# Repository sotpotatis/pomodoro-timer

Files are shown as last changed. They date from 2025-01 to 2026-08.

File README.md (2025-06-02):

# Pomodoro Timer

## What is this?

This Project aims to create a portable Pomodoro timer that you can carry around with you - regardless if studying in the library, on the bus, or in the Comfort of your own home!

### Components and technology

#### Programming languages

The main part of this Project is programmed in AVR Assembly. Some parts are coded in C.

#### Main Components used

* Attiny84A

* DS3231 timer

#### Building the Circuit/assembling the PCB

For the full description on how to build the Project, I will at some Point (**TODO**) provide documentation about how to assemble your own Pomodoro timer.

## Development

Under the `code` folder you will find a solution which you can import into Microchip Studio (version 7).

You also need to add the files `i2cmaster.h` and `i2cmaster.S` which are from Peter Fleury's I2CMaster library (can be found [here](http://www.peterfleury.epizy.com/avr-software.html?i=1))

Inside `tests` you will find various tests carried out during the project - please see the `README` inside that directory.

## Documentation

See the `docs` folder for Project documentation.

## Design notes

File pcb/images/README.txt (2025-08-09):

This directory contains all the images that are used (as silkscreen items) on the PCB.
It also contains project files to so you can modify the images.

# Regarding the icons underneath the buttons

After loading the icons in the KiCads bitmap converter, set "Lock height/width ratio" to True and set "Width" to 12mm. This will give you the same sizing as is used on the board.

# Regarding `bell_icon`

After loading the icons in the KiCads bitmap converter, set "Lock height/width ratio" to True and set "Width" to 1.75mm. This will give you the same sizing as is used on the board.

*The bell icon is from [Pictogrammers](https://github.com/Templarian/MaterialDesign) and released under an Apache 2.0 License.*
See [https://github.com/Templarian/MaterialDesign/blob/master/LICENSE](here).

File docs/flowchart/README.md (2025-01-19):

# Flowchart files

Here you are going to find a flowchart of how the main timer logic is laid out. What does what? Look here to find out!

The flowchart can be imported to https://app.diagrams.net.

**Note** that the PDF version is less likely to be up-to-date (reflect the current version of the flowchart file) that the `.drawio` version of the file.

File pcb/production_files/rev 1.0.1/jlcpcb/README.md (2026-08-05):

I used PCBWay (not JLCPCB) when I ordered my Pomodoro Timer PCBs, becuase their assembly service was a bit cheaper for the setup I wanted (a blue or black PCB).

That said, the files in this directory should be "sendable" to JLCPCB. Use the following files:

* `rev1.0.1` is a .zip-file with all the gerbers

* `bom.xls` is the BOM file (for the assembly service)

* `sotpotatis_pomodoro_timer-all-pos.csv` is the positions file (for the assembly service)

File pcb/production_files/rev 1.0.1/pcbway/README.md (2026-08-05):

# Ordering instructions

If you want to order the PCB from PCBWay, here's what files to use:

* The file `gerbers_bom_and_cpl.zip` in `sotpotatis_pomodoro_timer.kicad_pcb` can be uploaded when requested to provide files related to the PCB (*not the assembly service*).

* The `.zip` file just mentioned includes both the BOM and CPL (i.e. the files required for the assembly service), but it turns out you need to supply them separately (PCBWay's upload form doesn't magically detect that you have provided a .zip file with both production and assembly files). Thus, *for the assembly service*, you should also upload `PCBWay_bom.csv` and `PCBWay_positions.csv` found in the `sotpotatis_pomodoro_timer.kicad_pcb` directory (or in the `.zip` file, it doesn't matter, they are the same files).

> For a visual image, see `sample_pcbway_order_information.png`. It shows a brief outlines of the files and settings I used when ordering the PCB.

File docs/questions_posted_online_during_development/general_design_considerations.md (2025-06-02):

Hello!

I am working on a project where I am trying to create a timer using an Attiny microcontroller.
I do not mention the model name of the Attiny, because it is not set in stone due to that I have a couple of different configurations in mind.

Let me explain the main goals and requirements of this project (skip to "the hardware I need to include" if you want to, the questions are related to those):

* Create a timer in the form factor of a credit card, powered by batteries (my plan is CR2032/26)
* The timer will allow counting down from 1 minute - 120 minutes.
* The time left will be displayed by using 12 LEDs arranged in a progress bar pattern. As the time left decreases, the number of lit LEDs decrease.
The last LED that is on in the pattern will be blinking every second to indicate countdown.
See the image here <ADD IMAGE> for what I mean:
* The user should allow setting 3 timer presets (for example, if you often count down to 30 minutes, you should be able to save it and load it)
* The timeout should be indicated by sounding a buzzer.
* The purpose of the timer is to be used for focus work sessions (e.g. studying on the go), so it is going to allow to user to select the time they want to work, 
the time they want to take a break, and how many times that should be repeated.
    * A consequence of the just mentioned requirement is that I want to add 3 LEDs on top of the 12 LEDs to indicate if the user is "working", "resting", or "setting the time".

Software requirements:
* For learning purposes, I would implement the main parts of the program in AVR Assembly. (Feel free to ramble as much as you want about that, but I have experience with C and I want to challenge myself.) (the I2C timer interaction, I'm doin' that in C. Don't worry.)

Thus, the hardware I need to include:

* 5 buttons (2 for timer settings (+/- time), 3 preset buttons) 
* 15 LEDs (12 for countdown time, 3 for timer state display)
* Timer
* Buzzer to indicate timeout

So to my questions.

# Question 1: Charlieplexing timer

## Background

Assuming the buzzer can be driven by some kind of square wave output from my timer (for example MCP7940M offers a 1Hz square wave output), I would need:

5 button GPIOs + 15 LEDs + 2 timer I2C GPIOs + 1 timer interrupt pin = 23 pins

A method to control n(n-1) LEDs with n pins is Charlieplexing. I am considering Charlieplexing the 12 pin progressbar, requiring a 4-pin setup. You can read all about it here: https://circuitdigest.com/microcontroller-projects/charlieplexing-arduino-to-control-12-leds-with-4-gpio-pins

So, I have come up with a code that works on an Arduino UNO for what I am trying to do: 

## Actual question

My "Charlieplexing" tests require a delay of 1000us to lit all LEDs without them appearing blinking to the human eye.
I was considering using an external timer to generate 1000us interrupts, but I can't find such timer and I assume that would be too fast for the device to handle.
How bad is it to use the internal Attiny timer for such short periods? The specs hint that it is quite inaccurate. Any alternatives I should consider? If precise timing isn't used, since Charlieplexing requires turning on and off LEDs super fast each second so all LEDs appear lit to the human eye, the LEDs appear to have different brightness.

And yeah, Charlieplexing requires turning on and off LEDs super fast each second so all LEDs appear lit to the human eye. I assume this rapid on/off would draw more power than just having them on all the time?

# Question 2: Charlieplexing - other alternatives

I may considering changing to shift registers, they seem easier. Read question 1 for more context. Anyone have experience controlling 12 GPIOs with less than 12 pins (in my case Charlieplexing allows me to use 4)? What other alternatives should I consider? How much better is shift registers?

# Question 3: External timer choice

I am planning on counting down the timer by generating timer interrupts every second to an interrupt pin, making the device decrement a "time left" variable. I also need the timer to beep a buzzer every second once the timer has run out.

I am currently considering the MCP7940M timer: does anyone have experience? And it would cost as many pins to use I2C as to connect a crystal to the Attiny and use the internal timer, so I am considering doing that instead. Is it visable?

# Question 4: Button interrupts

I want each of the 5 buttons to generate an interrupt if you click them. I've heard that hardware interrupts can be a pain with buttons unless you take some precautions. I have done research for question 1-3, but I admit this one not that much. Is it viable to use hardware interrupts for buttons? What precautions should I take when designing the hardware? Should I consider polling instead? I think that interrupts will be cleaner and more power efficient, hence why I am using that.

Sorry if this was a lot of questions, I'd be happy to just get an answer to a few of them :)

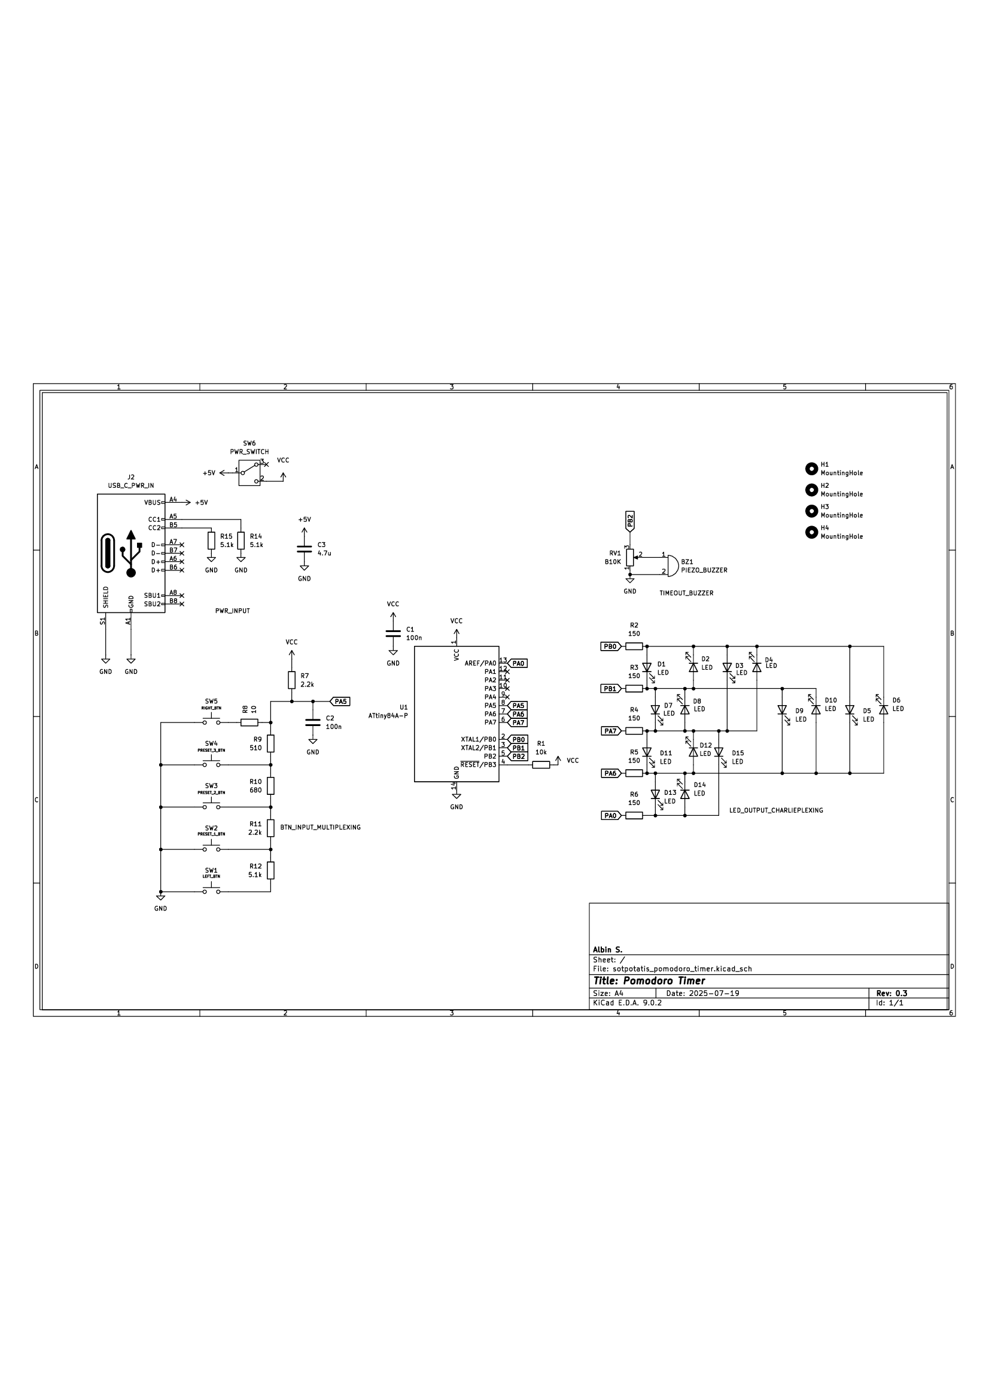
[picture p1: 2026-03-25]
pcb/pdfs/PCB reviews/Review 1 (rev1.0.0)/schematics 1 of 1.png

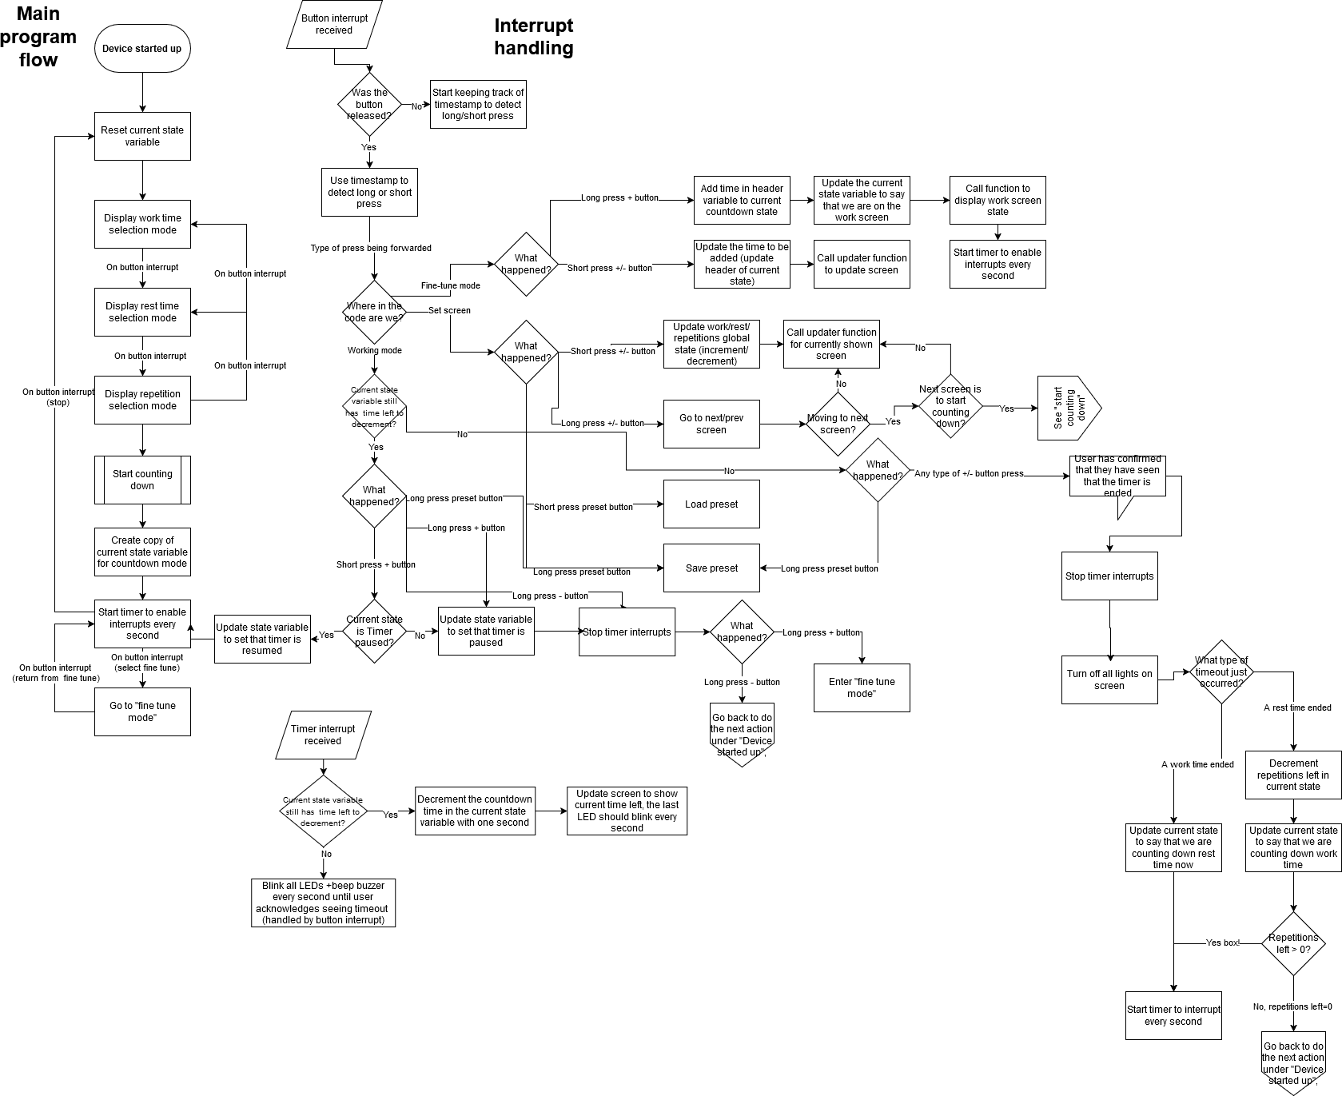
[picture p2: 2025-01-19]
docs/flowchart/Pomodoro timer flowchart.drawio.png

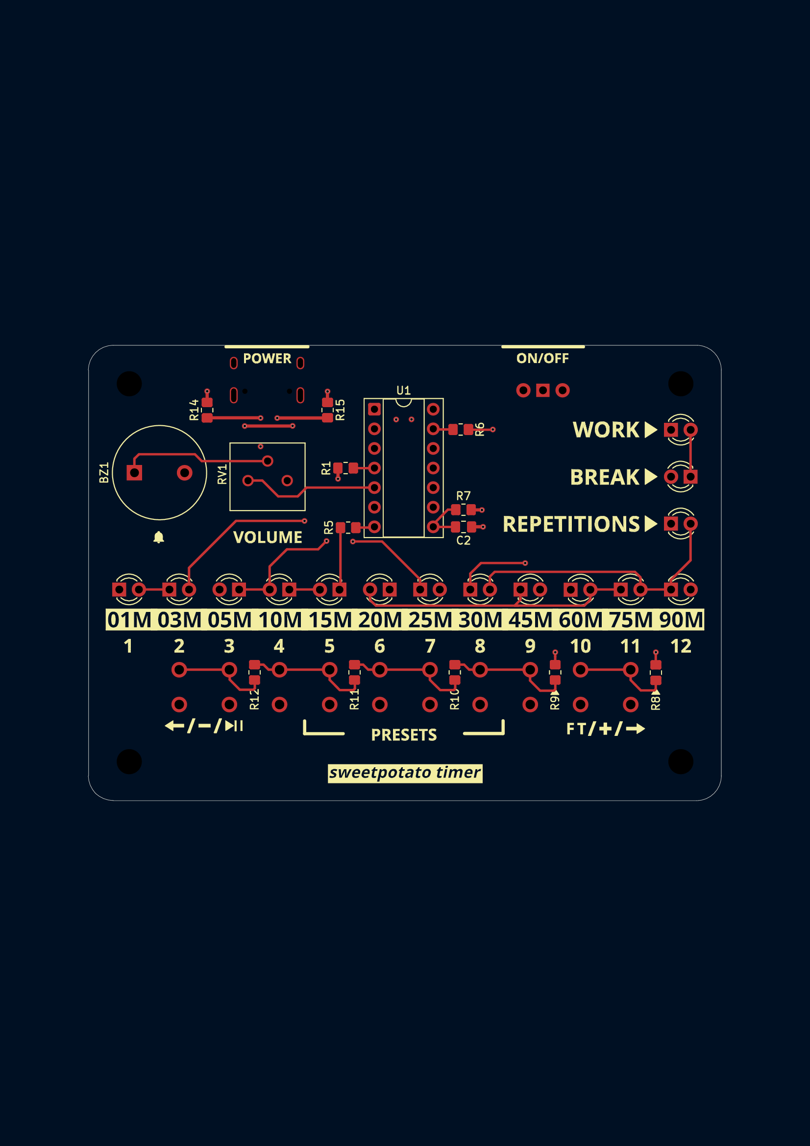
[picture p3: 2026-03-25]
pcb/pdfs/PCB reviews/Review 1 (rev1.0.0)/front-copper 1 of 1.png

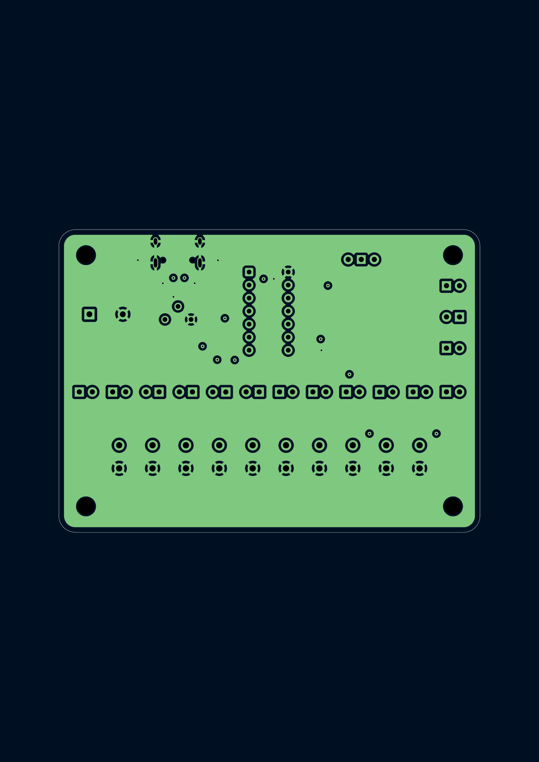
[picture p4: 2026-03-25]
pcb/pdfs/PCB reviews/Review 1 (rev1.0.0)/in1-copper 1 of 1.png

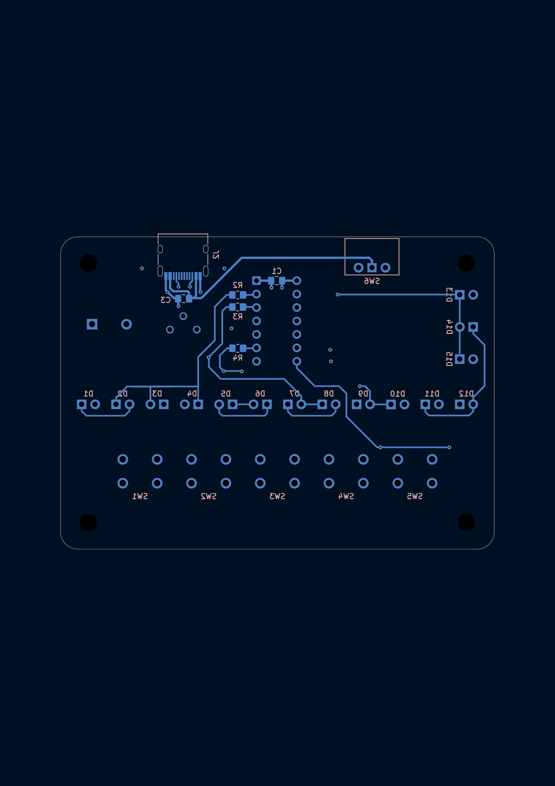
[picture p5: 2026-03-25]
pcb/pdfs/PCB reviews/Review 1 (rev1.0.0)/back-copper 1 of 1.png

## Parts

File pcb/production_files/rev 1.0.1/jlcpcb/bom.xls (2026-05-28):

Comment | Designator | Footprint | JLCPCB Part#(optional)
16P USB-C 2.0 | J2 | SMD-16P-USB-C | C165948
10kΩ | R1 | 0805_R | C17414
150Ω | R2-6 | 0805_R | C17471
2.2kΩ | R7,R11 | 0805_R | C17520
10Ω | R8 | 0805_R | C25278
510Ω | R9 | 0805_R | C17734
680Ω | R10 | 0805_R | C17798
5.1kΩ | R12,R14-15 | 0805_R | C27834
100nF | C1-2 | 0805_C | C28233
4.7uF | C3 | 0805_C | C1779

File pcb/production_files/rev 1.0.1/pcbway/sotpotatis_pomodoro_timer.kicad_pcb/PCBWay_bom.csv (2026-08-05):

Designator | Quantity | Value | Footprint | Package | MPN | Mount_Type | Description
C1, C2 | 2 | 100nF | Unpolarized_Capacitor_0805 | 805 | CL21B104KCFNNNE | smt | Ceramic Capacitor 100nF 100V X7R 0805
C3 | 1 | 4.7uF | Unpolarized_Capacitor_0805 | 805 | CL21A475KAQNNNE | smt | Ceramic Capacitor 4.7uF 25V X5R 0805
J2 | 1 |  | USB_C_Receptacle_HRO_TYPE-C-31-M-12 | 16P USB-C | Hroparts TYPE-C-31-M-12 | smt | 20V 5A 16P Right-Angle USB2.0 Type-C Female Receptacle connector
R1 | 1 | 10kΩ | Resistor_0805 | 805 | 0805W8F1002T5E | smt | Resistor 150V 10kΩ ±1% 125mW 0805
R10 | 1 | 680Ω | Resistor_0805 | 805 | 0805W8F6800T5E | smt | Resistor 150V 680Ω ±1% 125mW 0805
R11, R7 | 2 | 2.2kΩ | Resistor_0805 | 805 | 0805W8F2201T5E | smt | Resistor 150V 2.2kΩ ±1% 125mW 0805
R12, R14, R15 | 3 | 5.1kΩ | Resistor_0805 | 805 | 0805W8F5101T5E | smt | Resistor 150V 5.1kΩ ±1% 125mW 0805
R2, R3, R4, R5, R6 | 5 | 150Ω | Resistor_0805 | 805 | 0805W8F1500T5E | smt | Resistor 150V 150Ω ±1% 125mW 0805
R8 | 1 | 10Ω | Resistor_0805 | 805 | 0805W8J0100T5E | smt | Resistor 150V 10Ω ±5% 125mW 0805
R9 | 1 | 510Ω | Resistor_0805 | 805 | 0805W8F5100T5E | smt | Resistor 150V 510Ω ±1% 125mW 0805

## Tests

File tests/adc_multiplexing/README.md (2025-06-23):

# ADC multiplexing tests

The files in this directory are as follows:

1. `adc_muliplexing_schematics.fzz` - A Fritzing project which has the schematics of the ADC multiplexing circuits and a stripboard translation of it.
However, it has never been built, so it might be incorrect.

> **ℹ️Note:** The main algorithm for ADC multiplexing was taught to me by patient AVRFreaks forums user `avrcandies`. I thank you very very much for the help!
> [This is the topic that they helped me in](www.avrfreaks.net/s/topic/a5CV40000003RbZMAU/t400824?page=2).

2. `Arduino Tests` - Contains test sketches used on an Arduino Uno to validate the multiplexing circuit and the actual algorithm.

3. `C Code, migrated to ASM nowadays` - Contains source code of `getCurrentADCButton` and `updateButtonStates` functions before they were translated to Assembly. 
Their Assembly translations have made it into the "real" source code, see adcMultiplexing.S.

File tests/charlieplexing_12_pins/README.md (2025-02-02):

# Charlieplexing 12 pins

For controlling each of the LEDs that are used for indicating the time left on the timer without having to use 12 pins for 12 LEDs, I used a technique called Charlieplexing.

Below is an explanation of the different files in this directory:

* `code/charlieplexing_12_leds/charlieplexing_12_leds.ino`: Code to test Charlieplexing up to 12 LEDs, with the last LED blinking. Proof of concept, does not neccessarily have to run on an Attiny microcontroller.

* `schematics/Charlieplexing 12 LEDs.fzz`: Fritzing project to build Charlieplexing 12 LEDs. Has a schematic grouped by pin, however, the breadboard is not cleanly routed and all connections are not correct. I must have done something wrong since Fritzings routing did not cooperate with me. **The breadboard layout in this file is not buildable**.

* `schematics/Charlieplexing 12 LEDs - Cleaned up breadboard version.fzz`: See  `schematics/Charlieplexing 12 LEDs.fzz`. The difference is that here, I routed the connections manually, **so this file is the one who has what I think is a somewhat understandable and buildable 12 LED charlieplexing circuit**.

* `schematics/Charlieplexing 12 LEDs - Alternative version with classical schematics.fzz`: Fritzing project to build Charlieplexing 12 LEDs. Breadboard connections unrouted. The interesting tab here is the "Schematics" tab, where a classical 4-pin Charlieplexing schematic is drawn, in the typical way that these schematics are drawn (not grouped by pin as for the other `.fzz` files, which are more intuitive for breadboard or routing in my opinion.)

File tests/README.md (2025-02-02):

# Tests folder

Here you will find out various tests carried out throughout the project. Please see the `README` files of each respective folder for more information.

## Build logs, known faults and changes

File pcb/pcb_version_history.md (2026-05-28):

# PCB version history

## rev1.0.1

* Same as rev1.0.0, *but* all SMD components have now been put on the back of the board. This was done in order to save assembly costs when using an Assembly Service (like JLCPCB)

## rev1.0.0

* Initial version of the Pomodoro Timer PCB.

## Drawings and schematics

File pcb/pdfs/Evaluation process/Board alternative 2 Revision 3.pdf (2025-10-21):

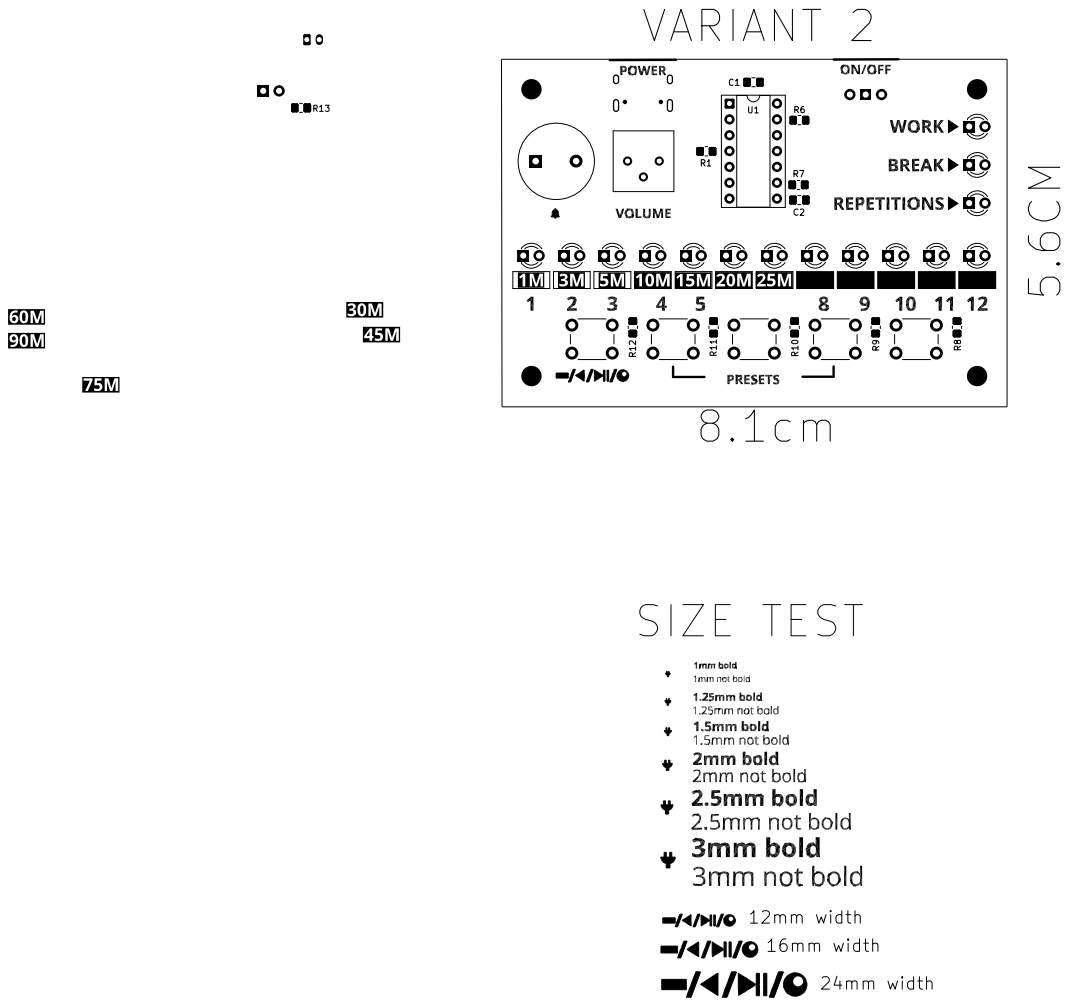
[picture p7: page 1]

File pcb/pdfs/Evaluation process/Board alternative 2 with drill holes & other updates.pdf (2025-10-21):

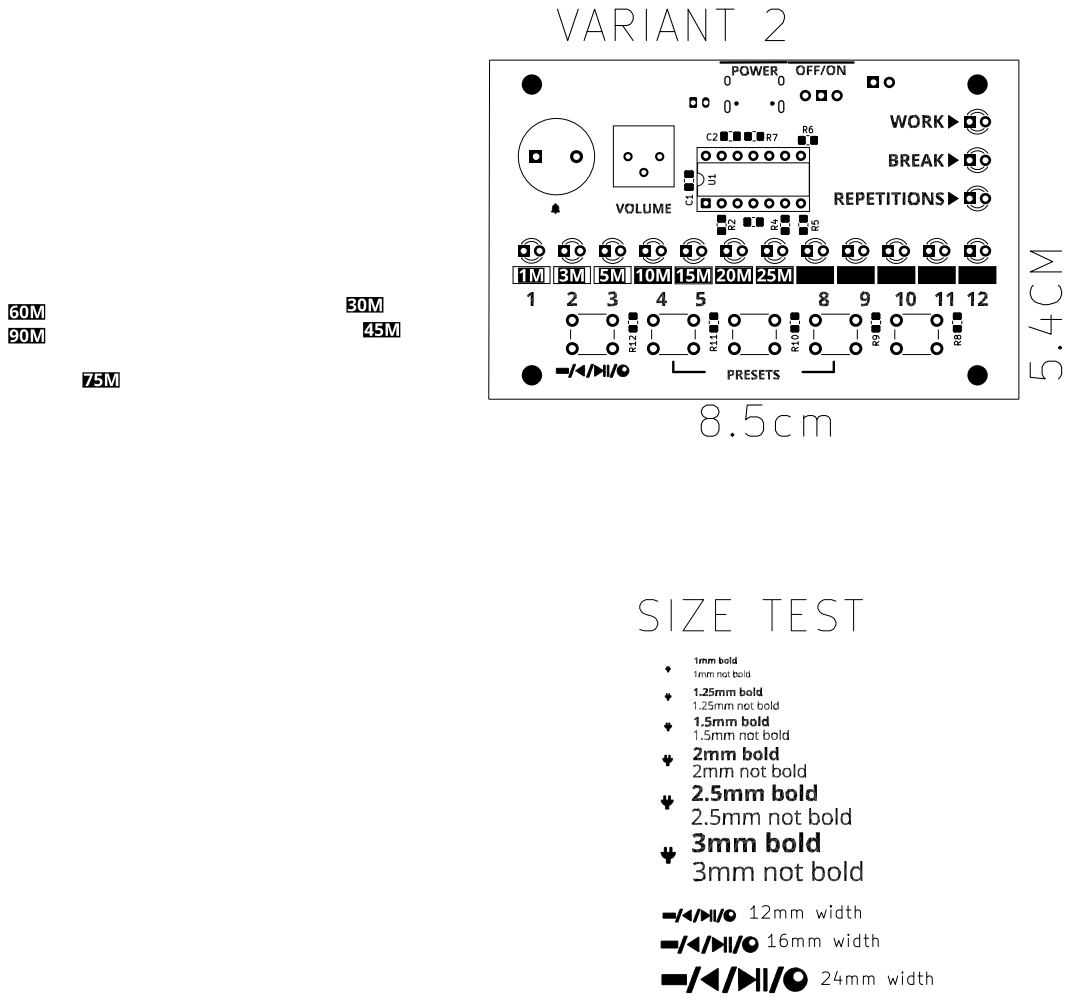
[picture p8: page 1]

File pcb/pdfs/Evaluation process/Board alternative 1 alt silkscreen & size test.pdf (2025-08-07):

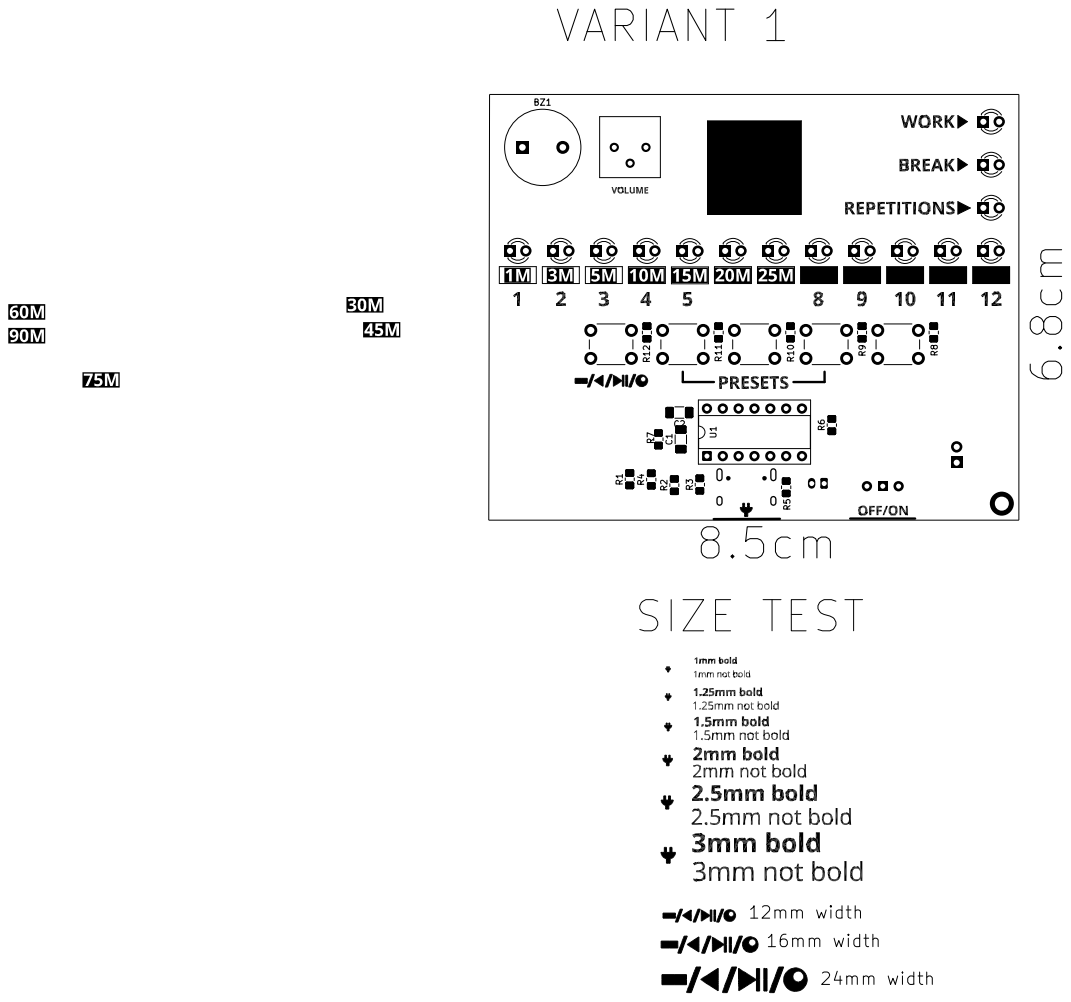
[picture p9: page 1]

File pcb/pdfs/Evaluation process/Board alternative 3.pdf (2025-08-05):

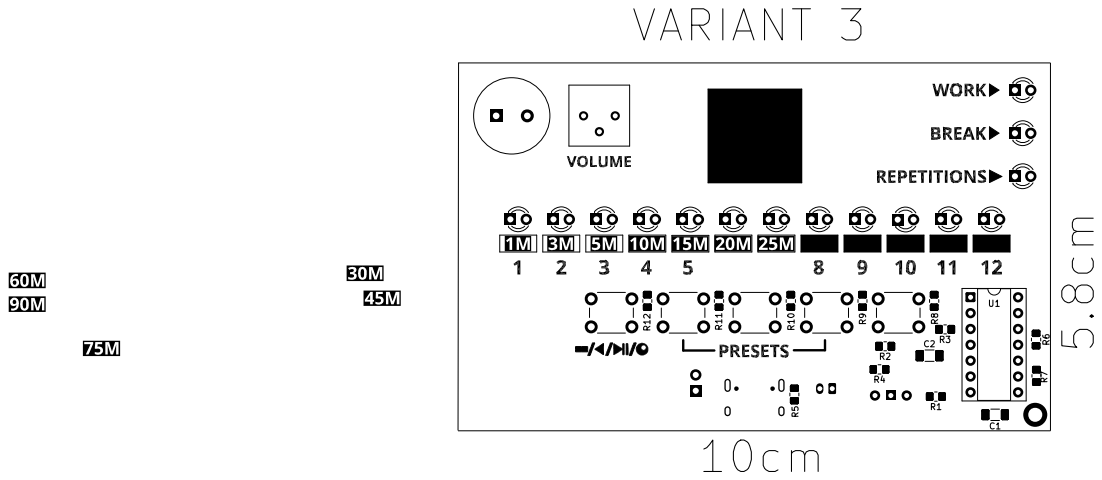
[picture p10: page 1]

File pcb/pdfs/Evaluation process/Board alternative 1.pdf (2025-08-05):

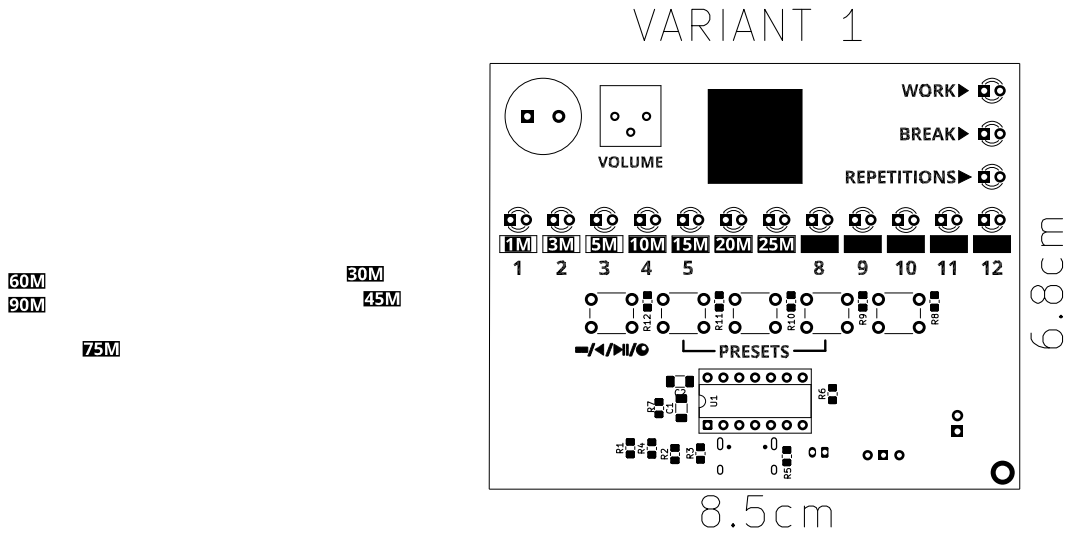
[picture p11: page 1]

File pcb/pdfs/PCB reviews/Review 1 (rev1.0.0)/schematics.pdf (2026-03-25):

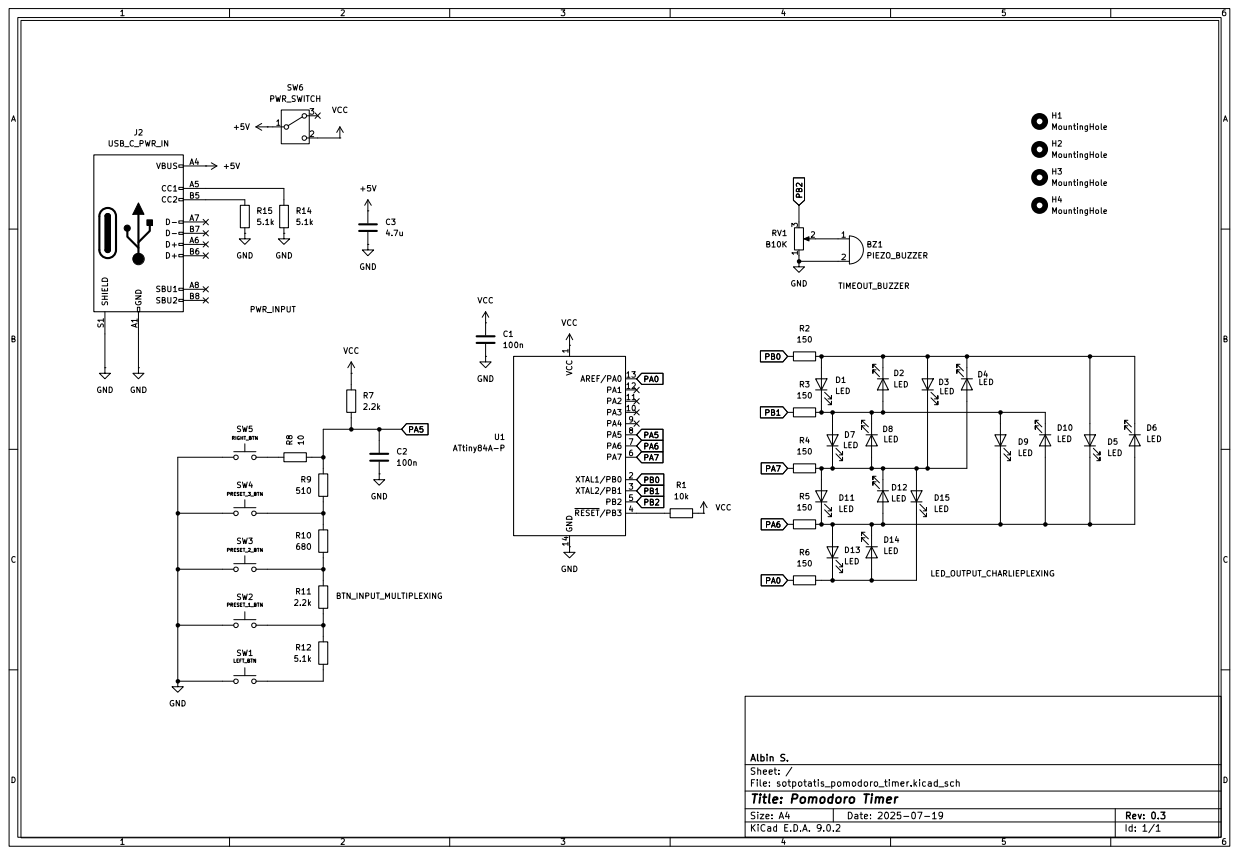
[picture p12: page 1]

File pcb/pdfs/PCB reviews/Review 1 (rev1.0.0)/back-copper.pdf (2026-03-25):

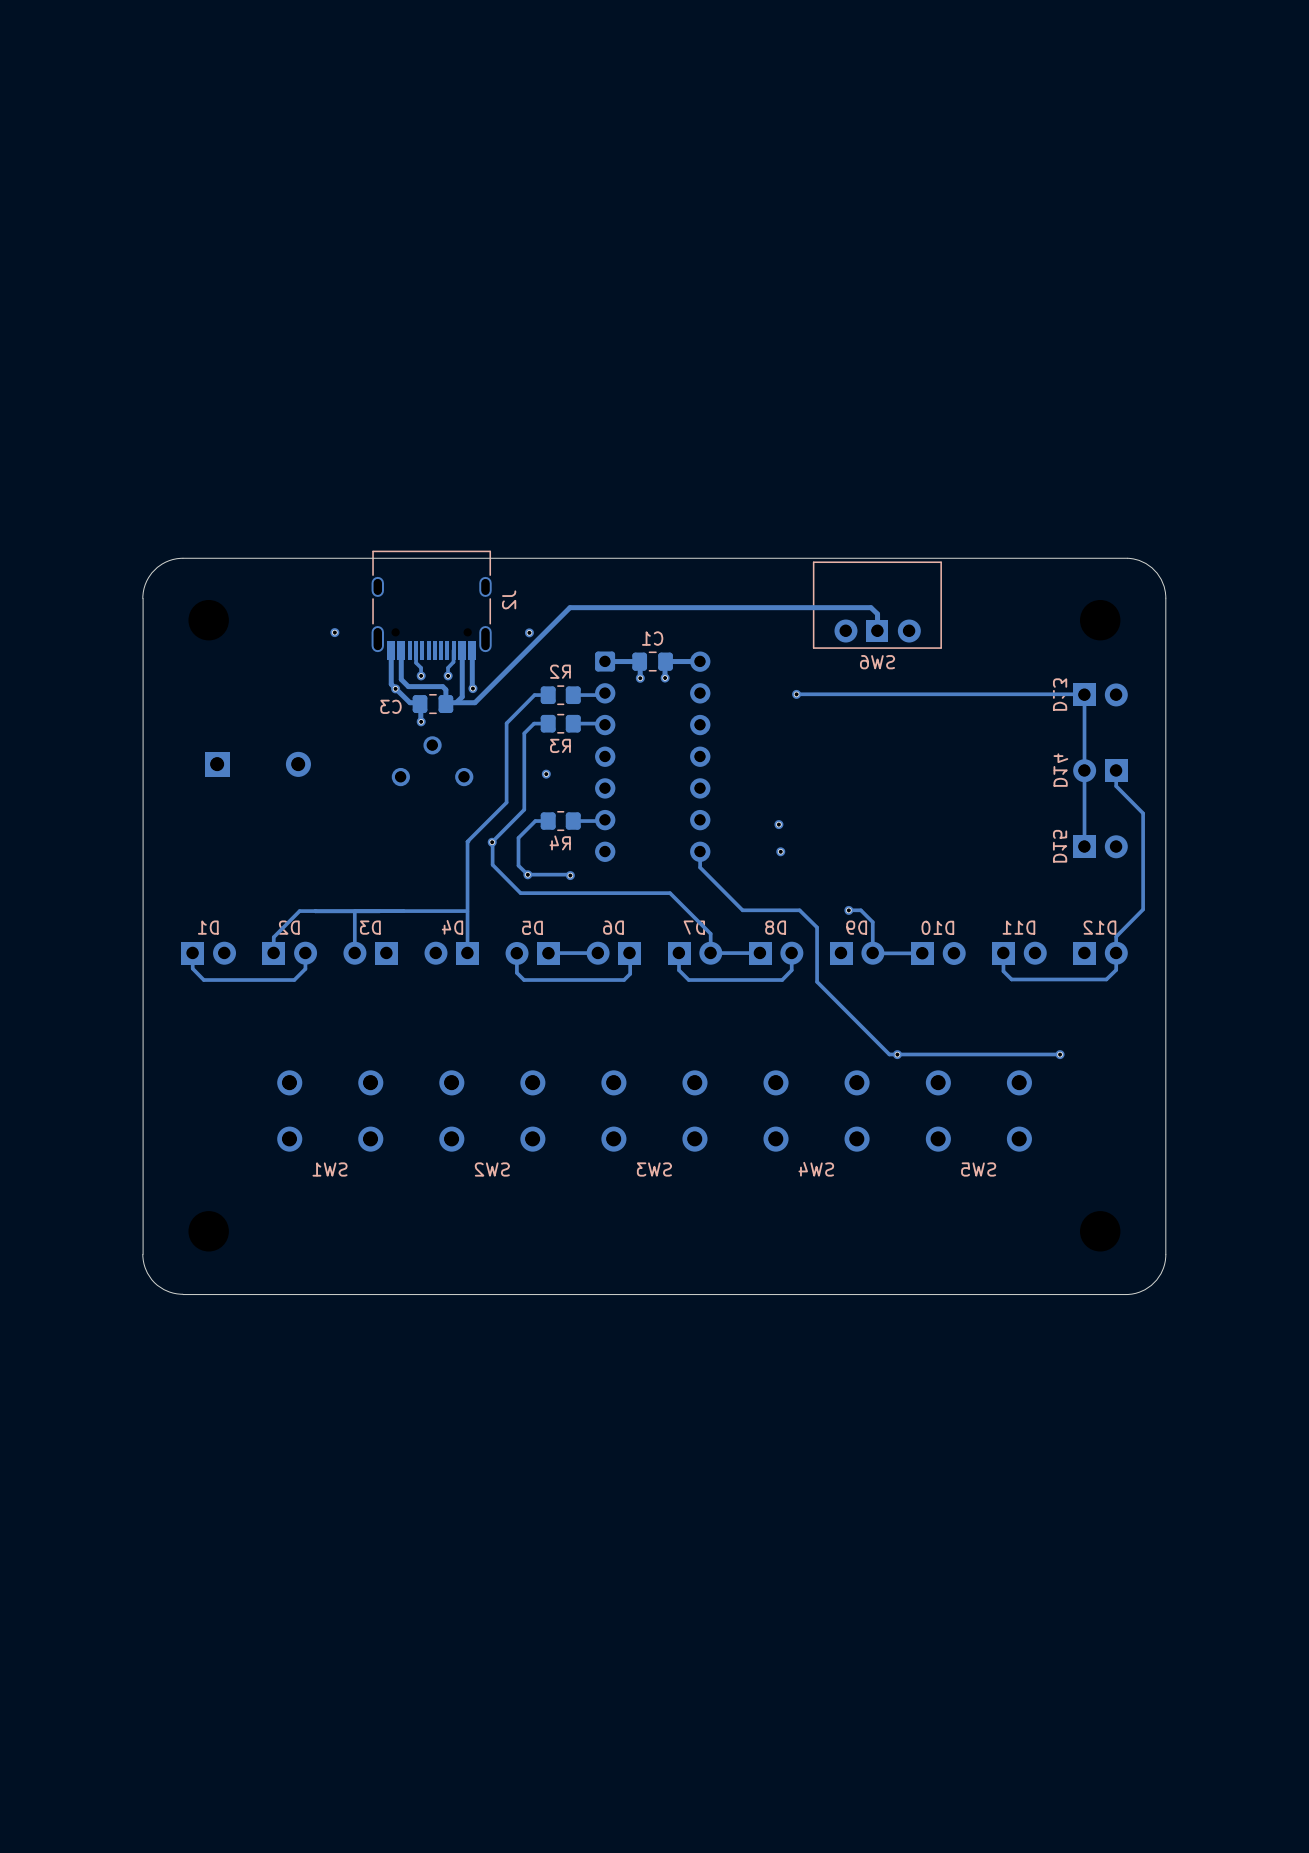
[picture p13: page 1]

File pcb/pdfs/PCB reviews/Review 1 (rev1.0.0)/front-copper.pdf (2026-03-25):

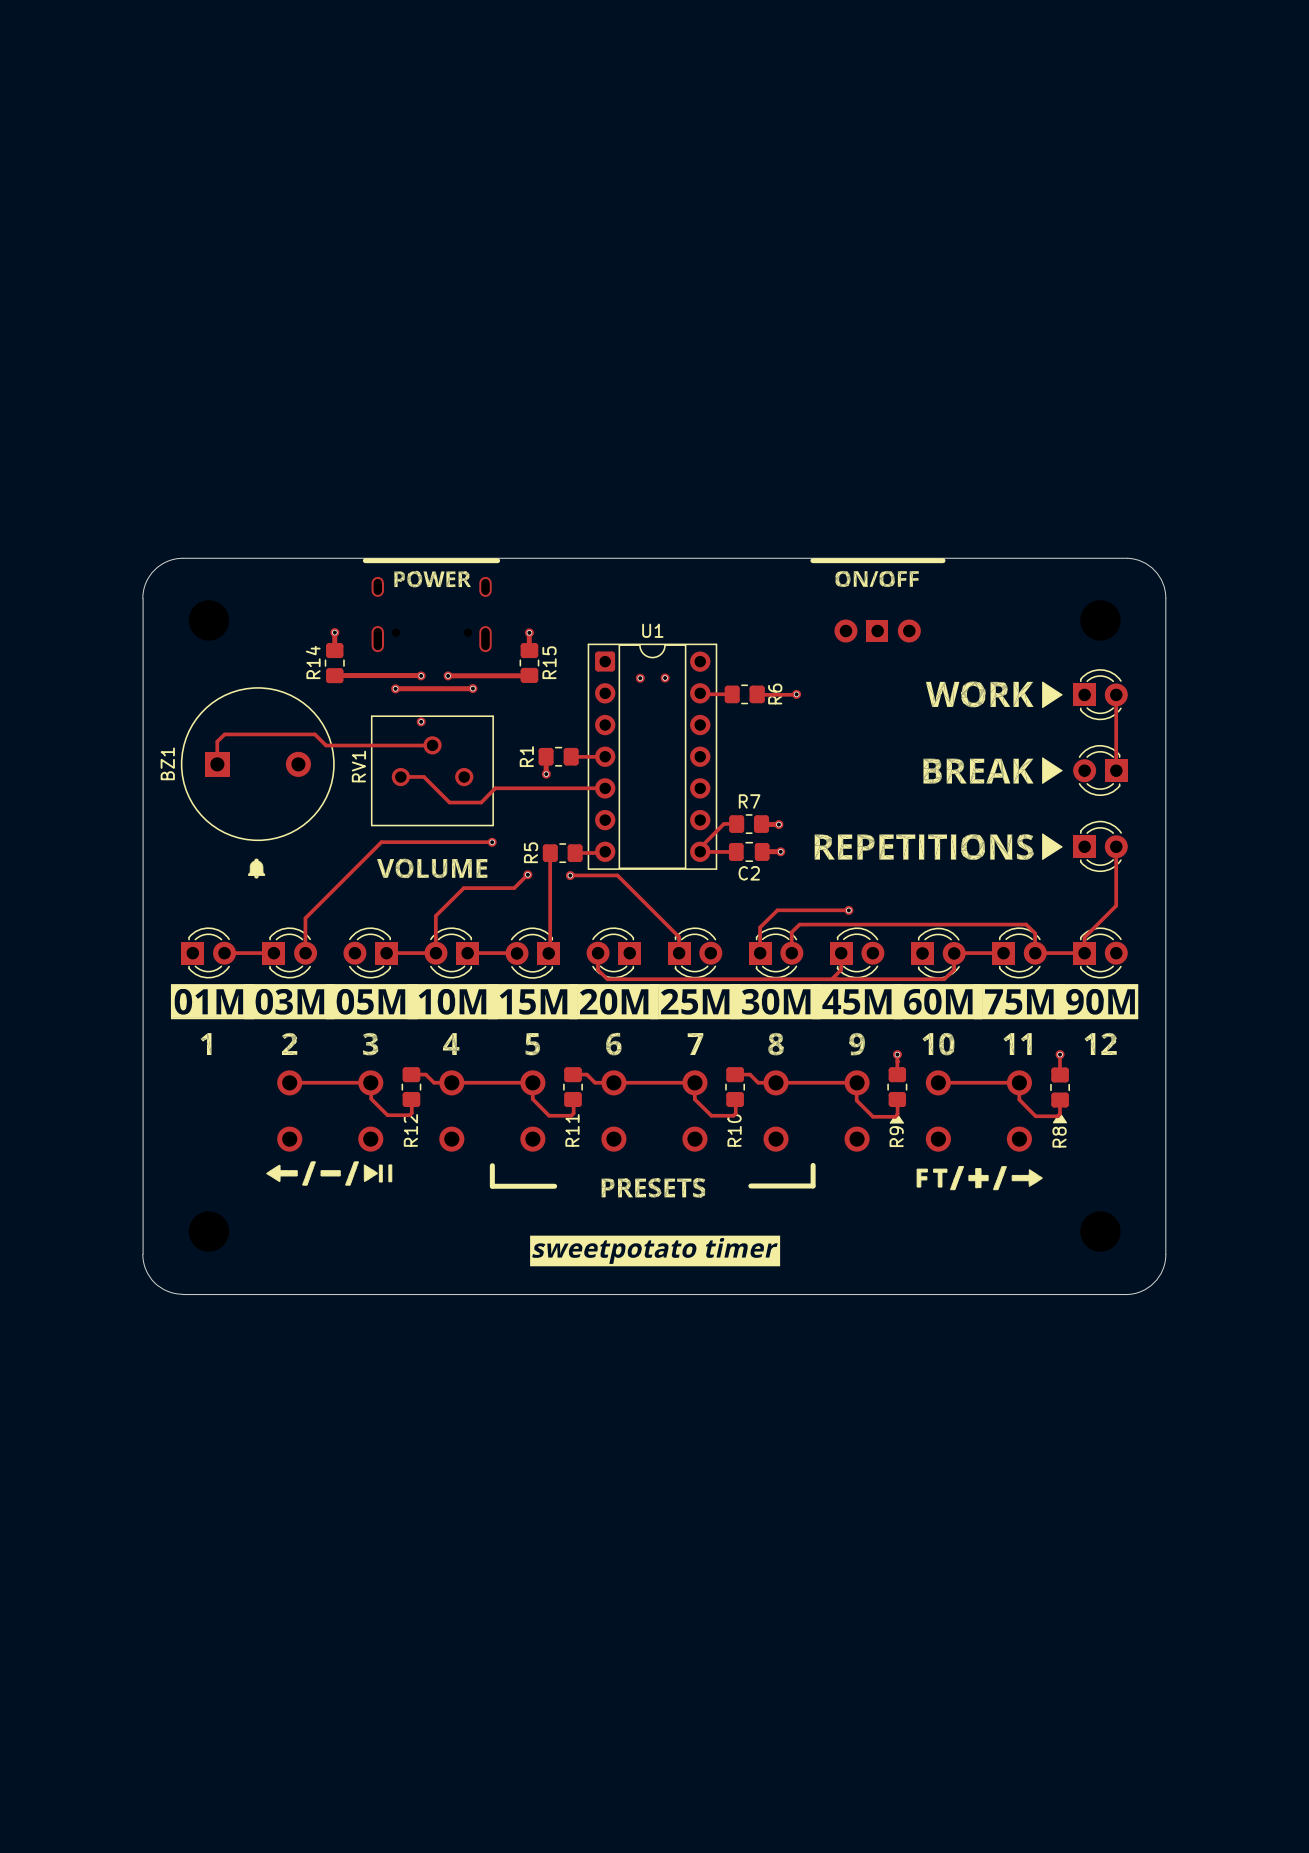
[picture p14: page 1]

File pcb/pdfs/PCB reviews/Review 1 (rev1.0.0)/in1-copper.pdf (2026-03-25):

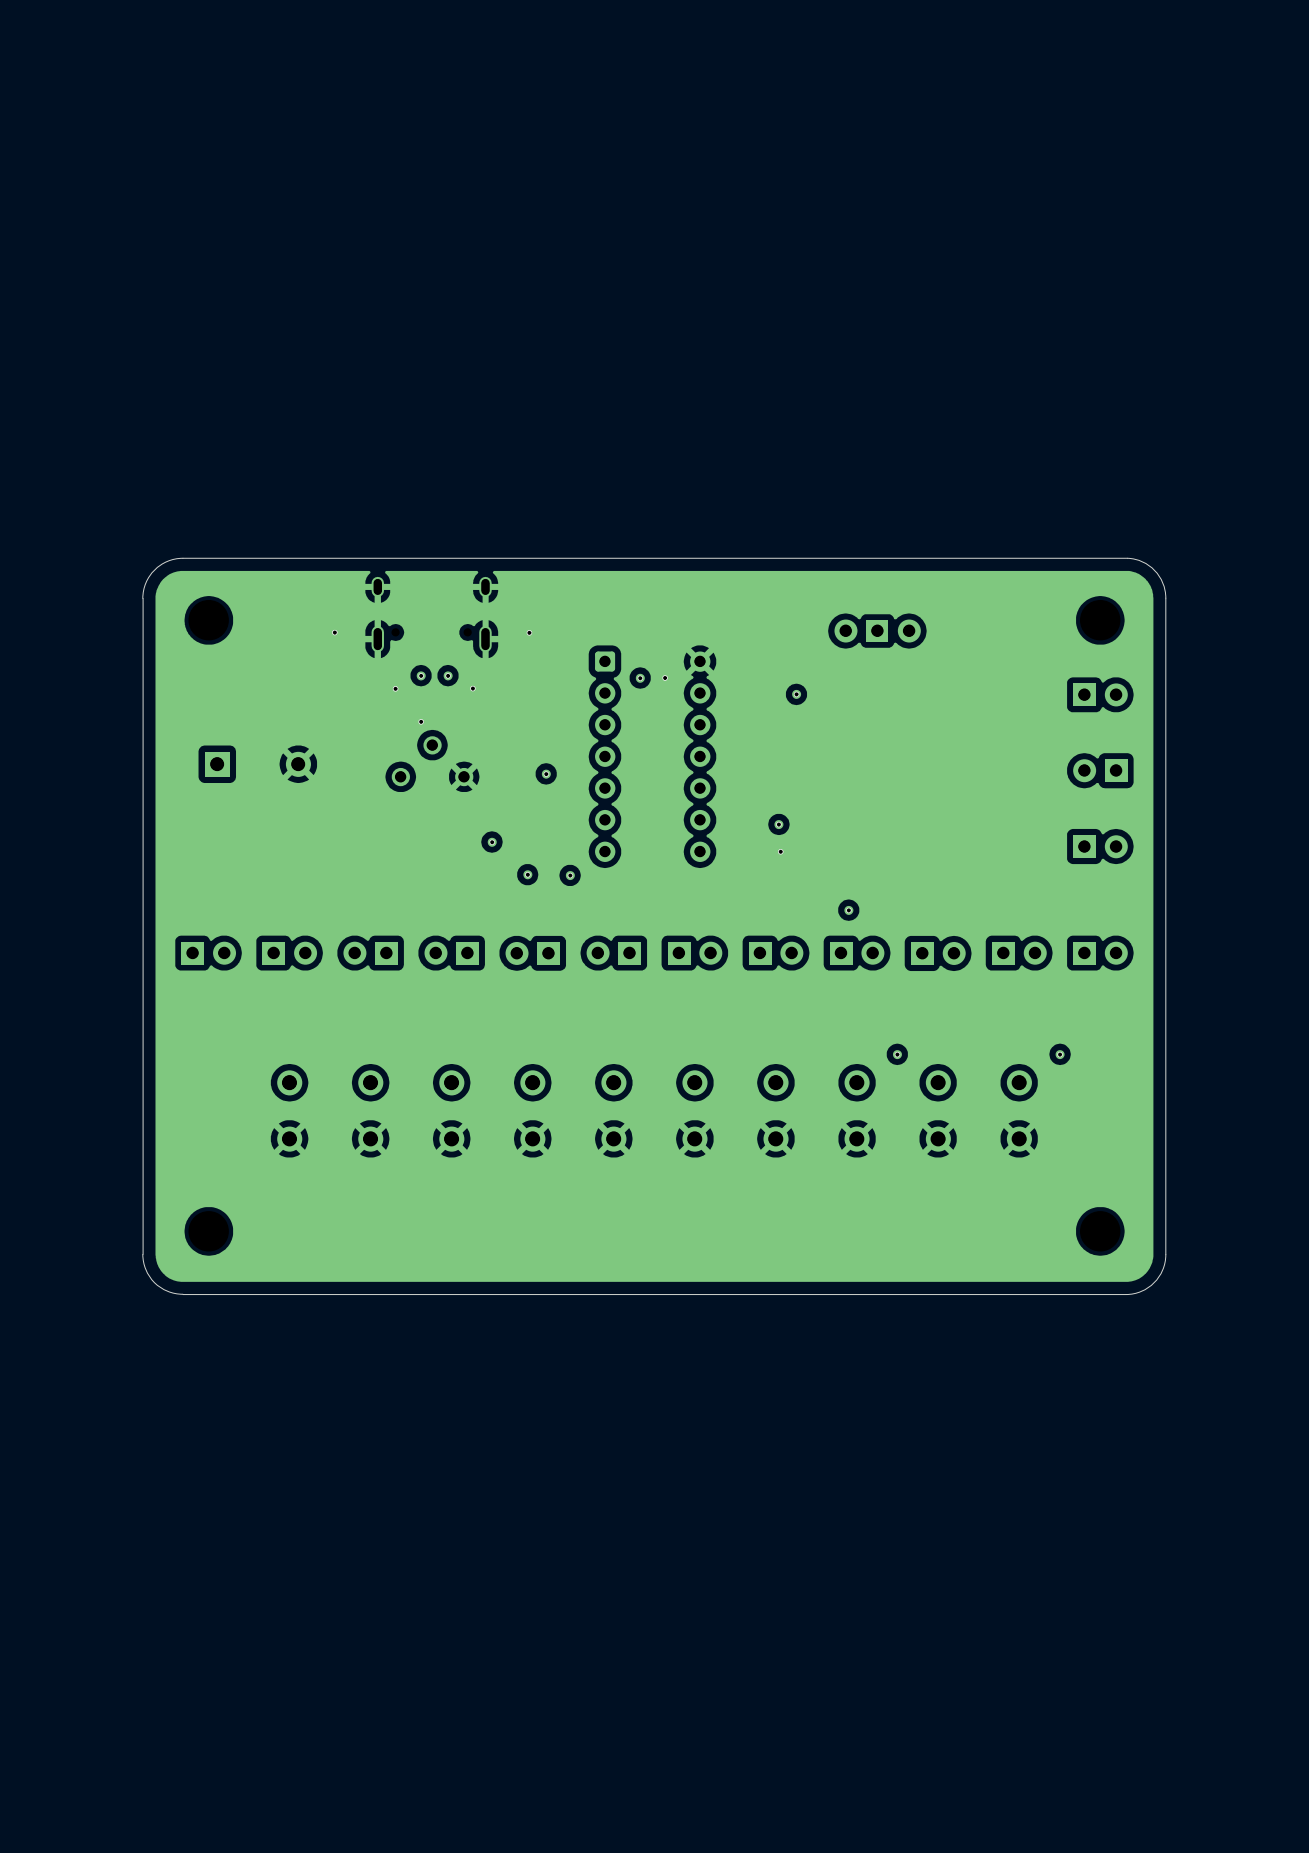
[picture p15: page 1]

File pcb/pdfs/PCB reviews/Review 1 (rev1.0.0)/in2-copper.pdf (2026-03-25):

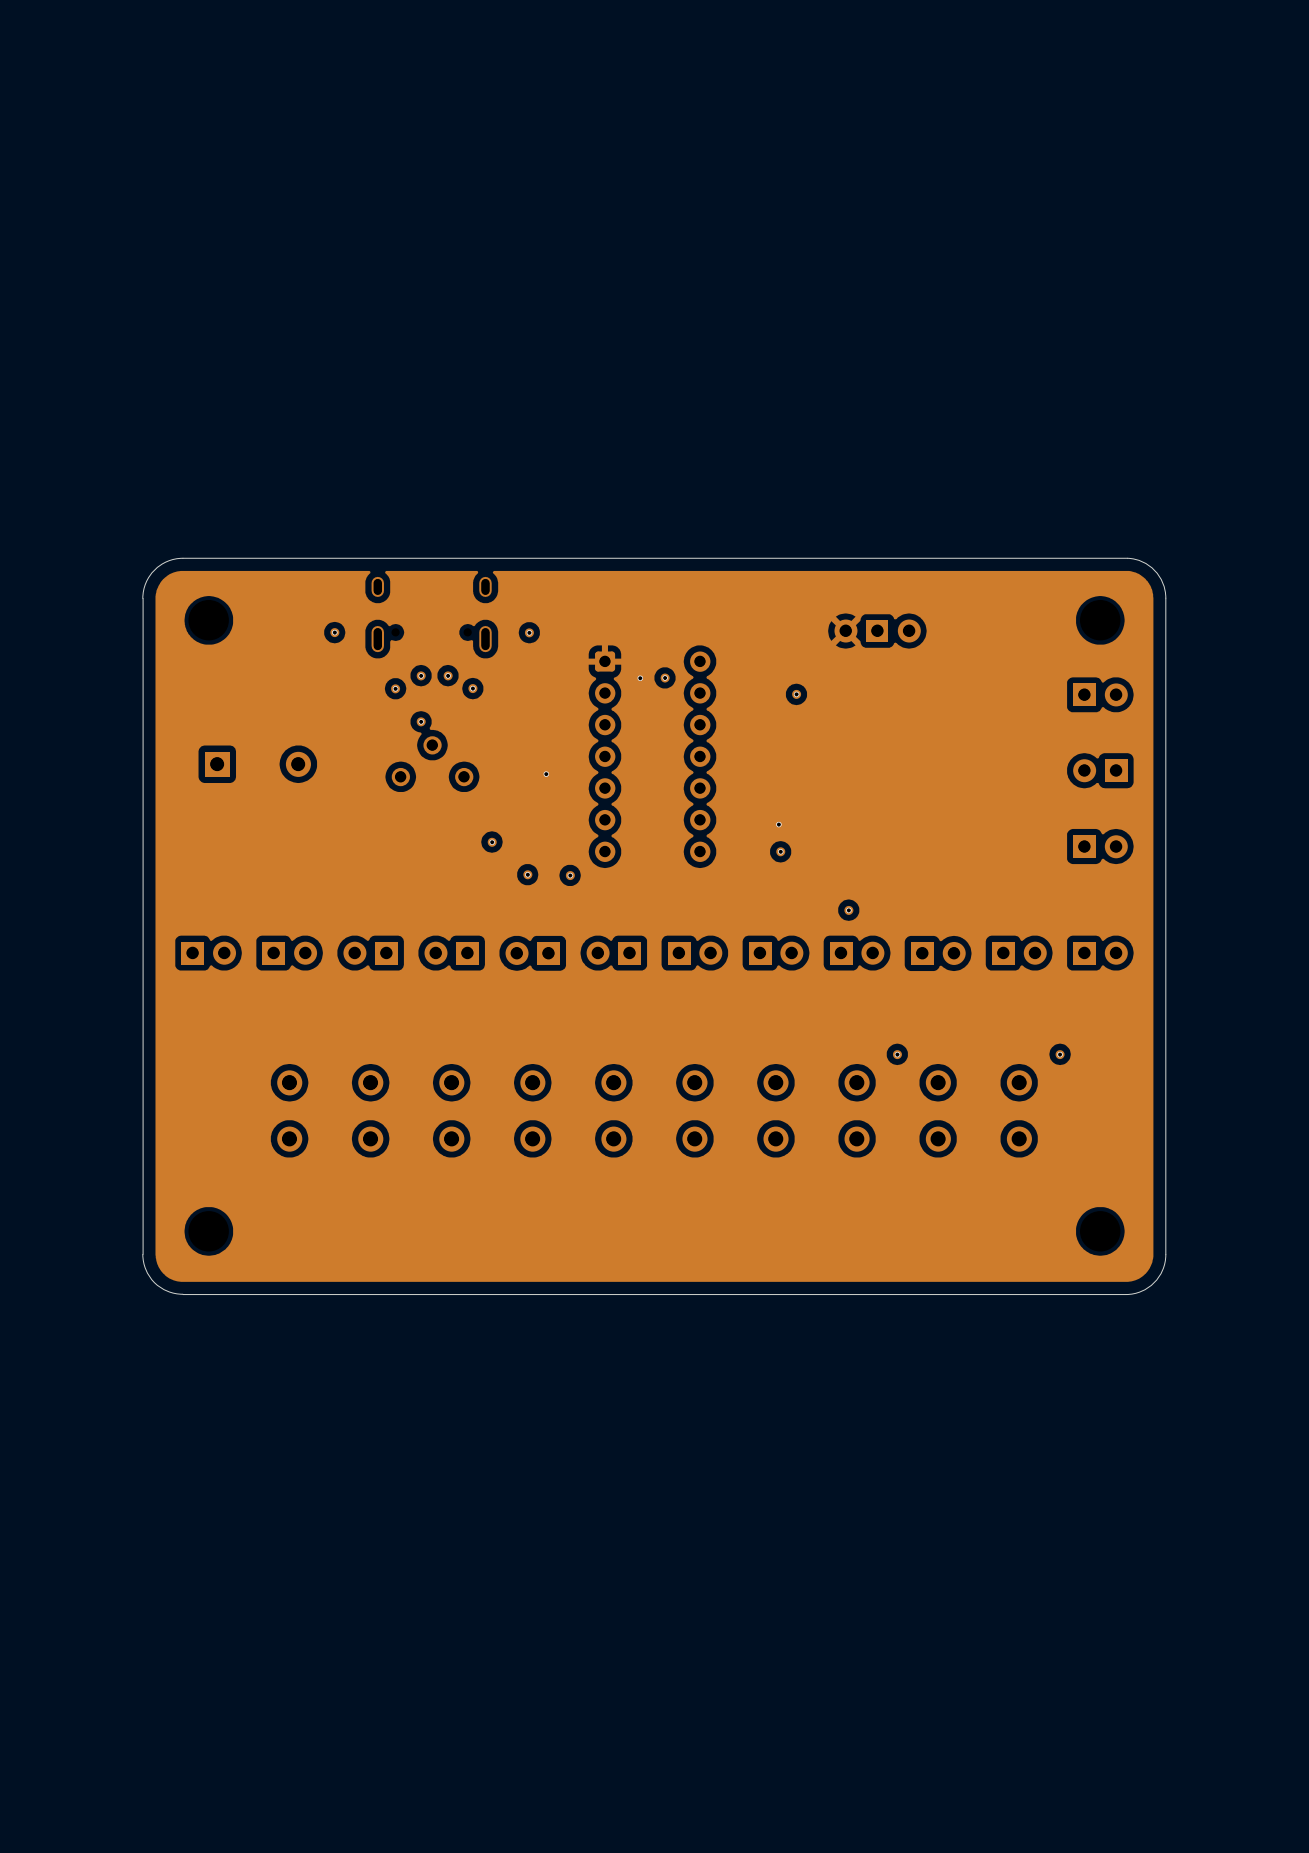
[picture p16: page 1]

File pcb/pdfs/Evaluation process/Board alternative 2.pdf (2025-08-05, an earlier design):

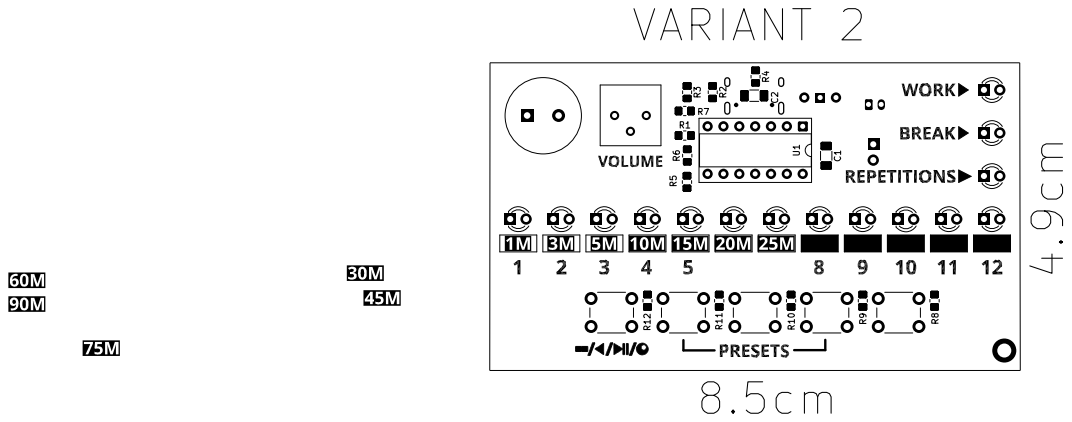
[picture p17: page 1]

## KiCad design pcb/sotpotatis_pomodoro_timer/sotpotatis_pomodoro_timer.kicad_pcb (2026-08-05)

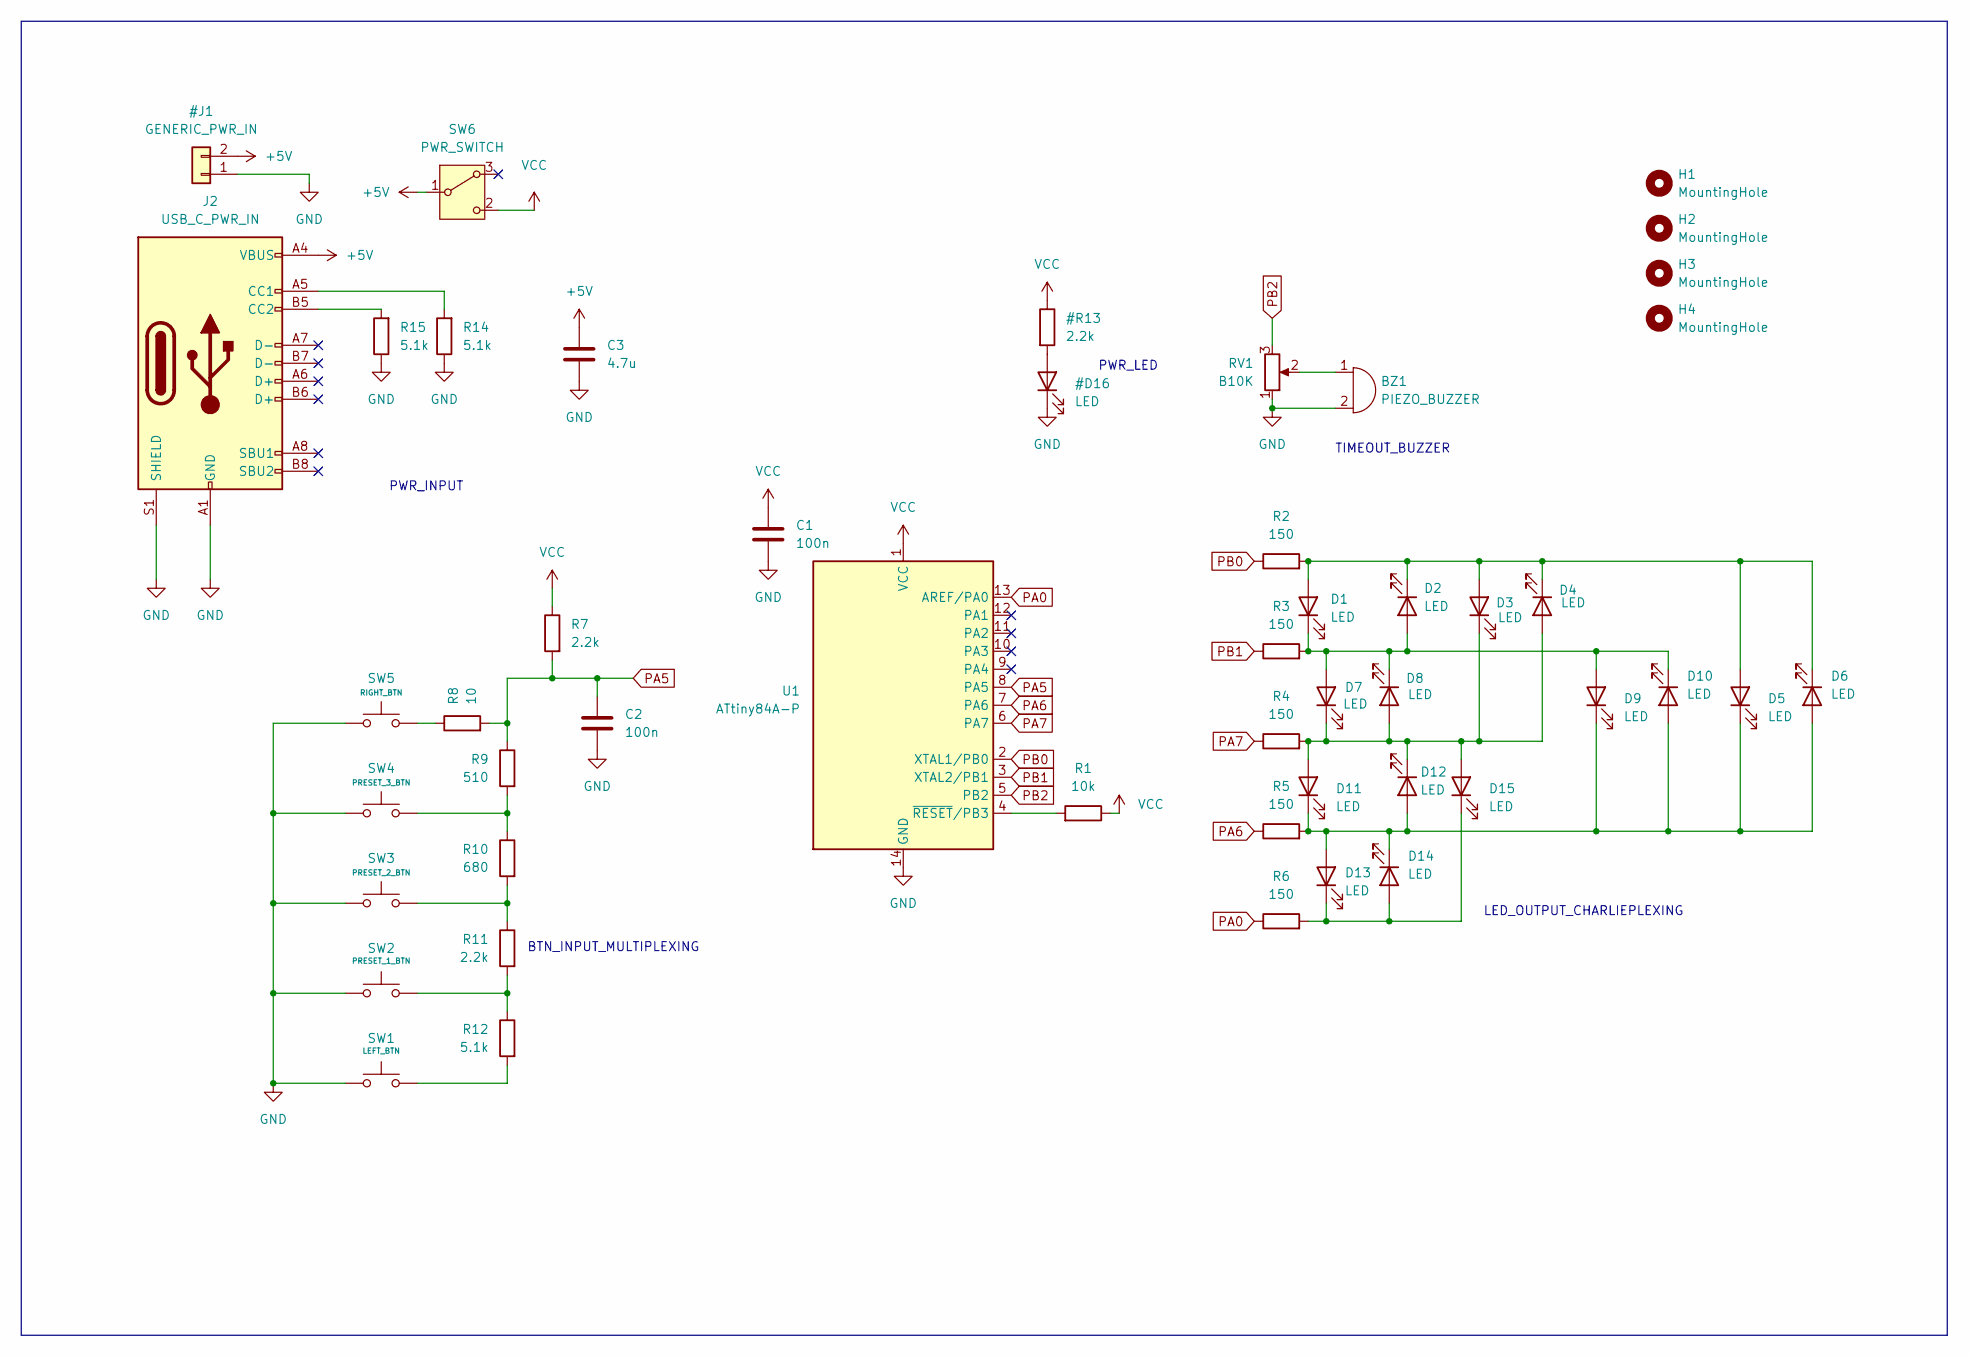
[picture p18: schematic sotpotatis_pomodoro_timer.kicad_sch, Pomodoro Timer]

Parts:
BZ1: PIEZO_BUZZER; Buzzer_12x5.5RM6.5
C1, C2: 100n; C_0805_2012Metric_Pad1.18x1.45mm_HandSolder
C3: 4.7u; C_0805_2012Metric_Pad1.18x1.45mm_HandSolder
D1, D2, D3, D4, D5, D6, D7, D8, D9, D10, D11, D12, D13, D14, D15: LED; LED_D3.0mm
H1, H2, H3, H4: MountingHole; MountingHole_3.2mm_M3
J2: USB_C_PWR_IN; USB_C_Receptacle_HRO_TYPE-C-31-M-12
R1: 10k; R_0805_2012Metric_Pad1.20x1.40mm_HandSolder
R2, R3, R4, R5, R6: 150; R_0805_2012Metric_Pad1.20x1.40mm_HandSolder
R7, R11: 2.2k; R_0805_2012Metric_Pad1.20x1.40mm_HandSolder
R8: 10; R_0805_2012Metric_Pad1.20x1.40mm_HandSolder
R9: 510; R_0805_2012Metric_Pad1.20x1.40mm_HandSolder
R10: 680; R_0805_2012Metric_Pad1.20x1.40mm_HandSolder
R12, R14, R15: 5.1k; R_0805_2012Metric_Pad1.20x1.40mm_HandSolder
RV1: B10K; Potentiometer_Bourns_3386P_Vertical
SW1: LEFT_BTN; SW_PUSH_6mm_H5mm
SW2: PRESET_1_BTN; SW_PUSH_6mm_H5mm
SW3: PRESET_2_BTN; SW_PUSH_6mm_H5mm
SW4: PRESET_3_BTN; SW_PUSH_6mm_H5mm
SW5: RIGHT_BTN; SW_PUSH_6mm_H5mm
SW6: PWR_SWITCH; SW_Slide-03_Wuerth-WS-SLTU_10x2.5mm_P2.54mm
U1: ATtiny84A-P; DIP-14_W7.62mm_Socket

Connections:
unnamed: BZ1.1 (+), RV1.2
unnamed: D1.2 (A), D2.1 (K), D3.2 (A), D4.1 (K), D5.2 (A), D6.1 (K), R2.2
unnamed: D1.1 (K), D2.2 (A), D7.2 (A), D8.1 (K), D9.2 (A), D10.1 (K), R3.2
unnamed: D5.1 (K), D6.2 (A), D9.1 (K), D10.2 (A), D11.1 (K), D12.2 (A), D13.2 (A), D14.1 (K), R5.2
unnamed: D3.1 (K), D4.2 (A), D7.1 (K), D8.2 (A), D11.2 (A), D12.1 (K), D15.2 (A), R4.2
unnamed: D13.1 (K), D14.2 (A), D15.1 (K), R6.2
unnamed: J2.A5 (CC1), R14.2
unnamed: J2.B5 (CC2), R15.2
unnamed: R8.1, SW5.1
unnamed: R9.2, R10.1, SW4.1
unnamed: R10.2, R11.1, SW3.1
unnamed: R11.2, R12.1, SW2.1
unnamed: R12.2, SW1.1
unnamed: R1.2, U1.4 (~RESET/PB3)
PA0: R6.1, U1.13 (AREF/PA0)
PA5: C2.1, R7.2, R8.2, R9.1, U1.8 (PA5)
PA6: R5.1, U1.7 (PA6)
PA7: R4.1, U1.6 (PA7)
PB0: R2.1, U1.2 (XTAL1/PB0)
PB1: R3.1, U1.3 (XTAL2/PB1)
PB2: RV1.3, U1.5 (PB2)

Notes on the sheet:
PWR_LED
BTN_INPUT_MULTIPLEXING
LED_OUTPUT_CHARLIEPLEXING
PWR_INPUT
TIMEOUT_BUZZER

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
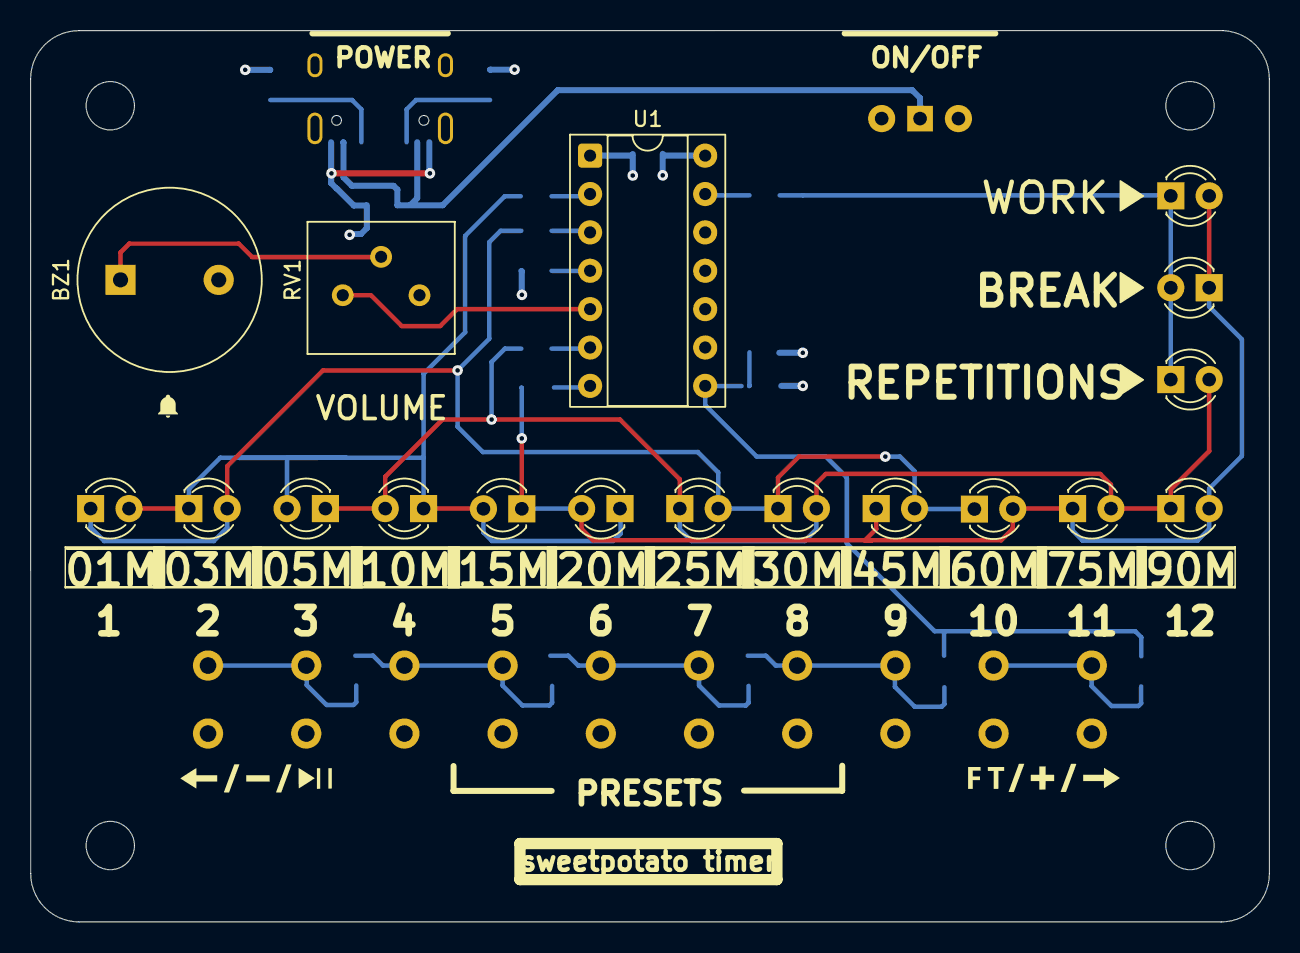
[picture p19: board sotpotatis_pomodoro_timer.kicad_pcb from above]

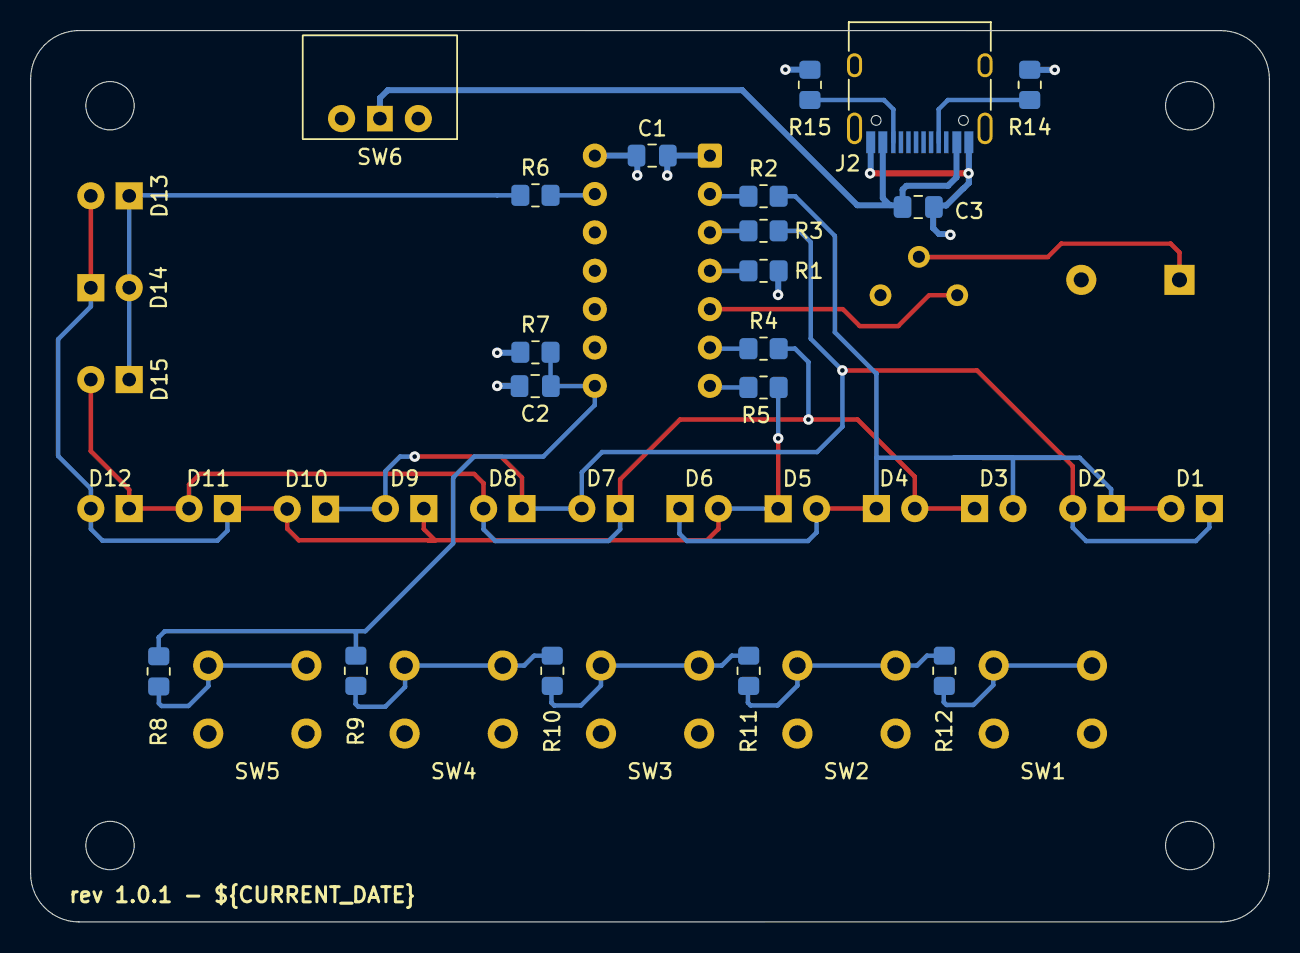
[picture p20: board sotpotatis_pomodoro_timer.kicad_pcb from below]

Board: 4 copper layers, 82.0 x 59.0 mm, 47 parts (19 on the bottom side), 24 nets.

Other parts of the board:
LB2: LOGO

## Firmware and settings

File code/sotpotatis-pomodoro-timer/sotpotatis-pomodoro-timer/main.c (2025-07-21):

/*
 *  main.c
 * Main code of the project
 */
#include "softwareConst.h"
#if RUN_TIMER_CALIBRATION == 0 && RUN_TIMER_TEST == 0
	#include "hardwareConst.h"


	#include "ledHandlers.h"

	#include "adcUtilities.h"

	#include "timerUtilities.h"

	#include <stdint.h>

	#include <avr/interrupt.h>

	#include "eepromUtilities.h"

	#include "buttonMultiplexing.h"

	// Global variables
	volatile uint32_t timestamp = 0;
	volatile uint8_t latestADCSample = 0; // The latest read sample
	volatile uint8_t latestADCSampleChecked = 1; // Whether the latest ADC sample was acknowledged by main or not.
	volatile uint8_t latestTimerTickAcknowledged = 1; // Flag that main can use to ack timer ticks

	/*
	Defines a custom ISR for ADC readings.
	*/
	ISR(TIM0_COMPA_vect) {
	  timestamp++;
	  latestTimerTickAcknowledged = 0;
	  if (timestamp % ADC_SAMPLE_RATE == 0 && latestADCSampleChecked) {
		clearADCInterrupts();
		latestADCSample = readCurrentADCValue();
		latestADCSampleChecked = 0;
	  }
	}



	// Store a numeric counter for each button that, for each reading: counts up (+1) if the ADC detects a voltage reading mapped to that button.
	// It counts down (-1) for all buttons that the ADC are not mapped to.
	uint8_t buttonCounts[5] = {
	  0,
	  0,
	  0,
	  0,
	  0
	};
	// Same as buttonCounts but for hold detection
	uint8_t debouncedCounts[5] = {
	  0,
	  0,
	  0,
	  0,
	  0
	};
	// Store whether buttons were debounced or not. See below for usage.
	uint8_t buttonDebounced[5] = {
	  0,
	  0,
	  0,
	  0,
	  0
	};
	// Store whether buttons were detected as held or not.
	// These flags are cleared by main.
	uint8_t buttonHeld[5] = {
	  0,
	  0,
	  0,
	  0,
	  0
	};
	// Store whether buttons were detected as tapped or not.
	// These flags are cleared by main.
	uint8_t buttonTapped[5] = {
	  0,
	  0,
	  0,
	  0,
	  0
	};

	int main(void) {
	  // Set up ADC on chosen pin, in Free Running Mode, with no Interrupts
	  // and the chosen prescaler
	  setUpADC(BUTTON_ADC_PIN, 0, 1, 0, ADC_PRESCALER_VALUE);
	  // Set up a timer in CTC mode, and generate interrupts
	  // every 1ms. Enable output compare pin on OC0A pin (PB2)
	  setPinStates(4, 1, 0);
	  setUpTimerInCTCMode(1, TICKS_PER_MS, TIMER_PRESCALER_VALUE, 1);
	  // Ensure all pins used for LED Charlieplexing are inputs.
	  resetAllCharlieplexingPins();
	  sei();
	  uint8_t currentIndex = 0;
	  uint8_t blink = 0;
	  uint8_t currentState = 0; // 0 = work, 1 = rest, 2 = repetitions
	  int8_t currentTurnedOffLED = -1;
	  uint16_t melodyTimeIndex = 0;
	  uint8_t melodyPauseIndex = 0;
	  uint8_t melodyPlaying = 1;
	  // Proof of concept code:
	  // lights up all 12 LEDs. If the user clicks the 5 button-panel,
	  // they should see the LED which corresponds to the button index that they just clicked
	  // turn off.
	  while (1) {
		// Set Charlieplexing LEDs to their current state.
		if (!latestTimerTickAcknowledged) {
			if (timestamp % 1000 == 0){
				// Blink the last LED on the panel every second
				blink = !blink;
			}
			// Turn on LEDs. Lower 12 are used for the ADC multiplexing demo. Upper 3 are used for the work / rest / repetition set
			// screen
			if (currentIndex < 12){
				if (currentTurnedOffLED != currentIndex && (currentIndex != 11 || !blink)){setCharlieplexingState(currentIndex);}
				currentIndex++;
			}
			else  {
				setCharlieplexingState(12+currentState);
				currentIndex = 0;
			}
			
			// Update the buzzer.
			// The buzzer plays a melody which is tracked using "melodyIndex". Just temporarily for testing.
			if (melodyPlaying){
				melodyTimeIndex++;
				if (melodyTimeIndex == 200){
					melodyTimeIndex = 0;
					melodyPlaying = 0;
					// Disable OCR0A to stop buzzer from sounding. 
					// Can be done in two ways - either by writing
					// to the timer register or by simply setting the pin to an input.
					// NOTE: I commented out the timer register writing method.
					// It caused a humming noise when the timer was not connected during my testing setup.
					setPinStates(4, 0, 0); 
					// setOutputComparePinA(0);
				}
			}
			else {
				if ((melodyPauseIndex  == 3 && melodyTimeIndex < 999) || (melodyPauseIndex < 3 && melodyTimeIndex < 100)){
					melodyTimeIndex++;
				}
				else {
					melodyTimeIndex = 0;
					melodyPlaying = 1;
					if (melodyPauseIndex < 3){
						melodyPauseIndex++;
					}
					else {
						melodyPauseIndex = 0;
					}
					// Reenable buzzer sound. Buzzer is connected to OCR0A pin.
					// Can be done in two ways - either by writing
					// to the timer register or by simply setting the pin to an output.
					// NOTE: I commented out the timer register writing method.
					// It caused a humming noise when the timer was not connected during my testing setup.
					setPinStates(4, 1, 0); // Set OCR0A to an output again
					// setOutputComparePinA(1);
				}
			}
			latestTimerTickAcknowledged = 1;
			// Process any new ADC samples to detect button preses
			if (!latestADCSampleChecked) {
				// No need to use a local copy of latestADCSample here as the ISR only updates it
				// when latestADCSampleChecked=1.
			 uint8_t currentADCButton = getCurrentADCButton(latestADCSample);
			updateButtonStates(buttonCounts,debouncedCounts, buttonDebounced,buttonTapped,buttonHeld, currentADCButton);
			  // Visually show on my LEDs what button that was detected as pressed
			  for (int i = 0; i < 5; i++) {
				if (buttonHeld[i] || buttonTapped[i]) {
				  buttonHeld[i] = 0;
				  buttonTapped[i] = 0;
				  currentTurnedOffLED = i;
				  // Update the current state, for illustrative purposes
					currentState++;
					if (currentState == 2){
						currentState = 0;
					}
				}
			  }
			  latestADCSampleChecked = 1;
			}
		}
		
	  }
	}
#endif

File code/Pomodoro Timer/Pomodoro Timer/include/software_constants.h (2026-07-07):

/*
 * software_constants.h
 * Includes software-related constants used throughout the project.
 */ 

#ifndef SOFTWARE_CONSTANTS_H_
	#define SOFTWARE_CONSTANTS_H_
		// ===== Timer constants =====
		// The clock selection to use for the timer, see bits CS[0:2] in TCR0B. Default is to use system clock but
		// with a prescaler of system clock / 64, which is equivalent to a the CS0:2 bits in TCR0B being set to 011.
		#define TIMER_PRESCALER_VALUE 0b011
		// Defines how many times the timer needs to tick up before 1 (one) ms has been reached.
		// This depends on your timer prescaler value and the clock frequency (see constants just above this)
		#define TICKS_PER_MS 124
		// Where to store the timer calibration value (in which EEPROM address). A low and a high bit is stored.
		#define TIMER_CALIBRATION_EEPROM_ADDRESS_H  3
		#define TIMER_CALIBRATION_EEPROM_ADDRESS_L  4
		#define RUN_TIMER_CALIBRATION 0
		#define RUN_TIMER_TEST 0
		// ===== ADC Button press detection constants =====
		// Button press detection is done via ADC, by sampling the ADC every n ms.
		#define ADC_SAMPLE_RATE 5 // The millisecond delay between each ADC sample. Must be >= 1ms due to how the code currently works
		#define ADC_PRESCALER_VALUE 7 // The prescaler to use for the ADC. Defaults to 7 (1/128 prescaler
		// There are two different press types that can be detected:
		// (1) TAPPED - A "quick" clickety click on the button.
		// (2) HELD - When the user holds down the button
		// The thresholds for these detections can be found below
		// Button n is declared debounced after the ADC matched the buttons voltage level
		// for DEBOUNCE_SAMPLE_LIMIT ADC samples.
		#define DEBOUNCE_SAMPLE_LIMIT 13
		// A button is declared held if it has been declared debounced = true for HOLD_SAMPLE_LIMIT number of
		// ADC samples.
		#define HOLD_SAMPLE_LIMIT 150
		// A button is declared tapped if it has been declared debounced = true for **maximum** TAP_SAMPLE_LIMIT number of
		// ADC samples.
		#define TAP_SAMPLE_LIMIT 80
#endif

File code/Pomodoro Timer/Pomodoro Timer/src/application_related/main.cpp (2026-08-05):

#include <avr/interrupt.h>
#include "../../include/application_related/Screens.hpp"
#include "../../include/application_related/ScreenSwitcher.hpp"
#include "../../include/hardware_related/leds/LEDController.hpp"

ISR(TIM0_COMPA_vect) {
// TODO
}

int main(){
	LEDController led_controller;
	ScreenSwitcher screen_switcher;
	Screens screens {led_controller, screen_switcher};
	screen_switcher.switch_screen(screens.startup_screen);
}

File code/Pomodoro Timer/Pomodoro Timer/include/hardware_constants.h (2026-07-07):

/* hardware_constants.h
Defines hardware-related constants.
*/
#include <avr/io.h>
#ifndef HARDWARE_CONSTANTS_H_
	#define HARDWARE_CONSTANTS_H_
		// This is part of <avr/io.h> and we need to redefine this for proper I/O address referencing
		#undef __SFR_OFFSET
		#define __SFR_OFFSET  0
		// ====== ADC Pin to use for button multiplexing ======
		// Note that ADC pins simply use the format defined by Microchip
		// (0-7 depending on if you want to use pin PA0-7)
		#define BUTTON_ADC_PIN 5
		// For Pure I/O pins (not ADC-pins), each "_PIN" definition follows the following format:
		// The Attiny24A has 12 GPIO pins. Starting from PA we define a 16 bit number:
		// 0bPA7|PA6....PA0|constant 0000 PB3|...PB0 (for example: 0b0000 0011 0000 0000 refers to PA0 and PA1)
		// Where one and only one bit is high to control one pin.
		// For instance, 0b0000 0001 0000 maps a label to PA0.
		// It points to a 2x integer list where the first element represents:
		// 0: The pin is connected to PORTA, 1: The pin is connected to PORTB
		// And the next entry in the list is the actual pin that is being used.
		// ====== LED pins ======
		// Note that we use LED Charlieplexing, so that one
		// pin controls 3 LEDs. The format of pin numbers is according to above,
		// that is why we left shift by 8.
		#define LED_CHARLIEPLEXING_PIN_1 0x0001 // PB0
		#define LED_CHARLIEPLEXING_PIN_2 0x0002 // PB1
		#define LED_CHARLIEPLEXING_PIN_3 0x8000 // PA7
		#define LED_CHARLIEPLEXING_PIN_4 0x4000 // PA6
		#define LED_CHARLIEPLEXING_PIN_5 0x0100// PA0
		// Operates only on 8 bit registers
		#define PA_PIN_MASK 0xFF
		#define PB_PIN_MASK 0x0F
#endif 

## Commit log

2025-01-23 add: Progress dump of (seemingly working) pin state functions
2025-02-02 add: Recent Charlieplexing attempts
    [Charlieplexing 12 LEDs - Alternate version with classical schematics.fzz, Charlieplexing 12 LEDs - Cleaned up breadboard version.fzz, Charlieplexing 12 LEDs.fzz]
2025-02-02 refactor: Move schematics for Charlieplexing tests to subfolder
    [Charlieplexing 12 LEDs - Alternate version with classical schematics.fzz, Charlieplexing 12 LEDs - Cleaned up breadboard version.fzz, Charlieplexing 12 LEDs.fzz]
2025-03-05 add: Lift some code outside of the loop in ledHandlers.S
2025-03-30 fix: Fully working Charlieplexing proof of concept!
    [main.c]
2025-05-19 add: ADC interrupts working!
2025-05-30 fix: Interrupts weren't properly coded. Now they are!
    [main.c]
2025-06-02 add: Working timer interrupts!
2025-06-12 add: Seeming working ADC multiplexing code
2025-06-12 fix: Reduce timing of hold
    [main.c]
2025-06-12 add: Tests for ADC multiplexing
    [adc_multiplexing_schematics.fzz]
2025-06-12 fix: Several cleanups across the whole project
    [main.c]
2025-06-14 fix: Cleanups across the whole code. Make tap detection have an upper limit.
    [main.c]
2025-06-19 fix: Ensure local copy of ADC value is used
    [main.c]
2025-06-21 add: ADC Multiplexing function now in ASM
2025-06-23 fix: Move old ADC Multiplexing code in C to its own file
    [adcMultiplexing.c, main.c]
2025-06-23 add: Charlieplexing for 15 LEDs tests
2025-06-23 add: Charlieplex 15 LEDs. Add buzzer proof of concept.
    [main.c]
2025-06-23 docs: Give credit for button multiplexing algorithm
2025-06-30 add: Timer calibration-related code
2025-06-30 docs: Fix spelling mistake in docstring
    [charlieplexing_15_pins.ino]
2025-06-30 docs: Add initial version of docs, which mention timer calibration
2025-07-04 add: First draft of Charlieplexing added to schematic
    [sotpotatis_pomodoro_timer.kicad_pcb, sotpotatis_pomodoro_timer.kicad_sch]
2025-07-04 fix: Remove temp & backup KiCad files from repo
    [sotpotatis_pomodoro_timer.kicad_pcb, sotpotatis_pomodoro_timer.kicad_sch]
2025-07-04 fix: Accidentally deleted a whole folder in prev commit
    [sotpotatis_pomodoro_timer.kicad_pcb, sotpotatis_pomodoro_timer.kicad_sch]
2025-07-07 add: ADC input pin multiplexing added to PCB
    [sotpotatis_pomodoro_timer.kicad_pcb, sotpotatis_pomodoro_timer.kicad_sch]
2025-07-11 fix: Buzzer rattlin' by using output compare pins instead
    [main.c]
2025-07-11 fix: Toggle output compare pin for buzzer via timer register instead of pin state
    [main.c]
2025-07-16 add: Initial version (0.1) of final schematics
    [sotpotatis_pomodoro_timer.kicad_pcb]
2025-07-16 add: Update schematic according to online feedback (v0.2)
    [sotpotatis_pomodoro_timer.kicad_pcb, sotpotatis_pomodoro_timer.kicad_sch]
2025-07-19 add: Current-limiting resistor to PCB (v0.2)
    [sotpotatis_pomodoro_timer.kicad_sch]
2025-07-19 fix: ADC multiplexing values were for pullup of 2k instead of 2.2k
2025-07-21 fix: Change constants to match final PCB pin usage
2025-07-21 fix: Humming when buzzer was not playing
    [main.c]
2025-07-21 add: USB-C power input (schematics rev 0.3)
    [sotpotatis_pomodoro_timer.kicad_pcb, sotpotatis_pomodoro_timer.kicad_sch]
2025-07-25 add: Fix footprints in PCB, start setting up DRC settings
    [sotpotatis_pomodoro_timer.kicad_pcb, sotpotatis_pomodoro_timer.kicad_sch]
2025-07-26 add: Finalize DRC settings, switch to 4-layer
    [sotpotatis_pomodoro_timer.kicad_pcb]
2025-08-04 add: Backup PCB progress. Working with placement.
    [freerouting.dsn, sotpotatis_pomodoro_timer.kicad_pcb, sotpotatis_pomodoro_timer.kicad_sch]
2025-08-05 add: Layout variant 1 of PCB
    [sotpotatis_pomodoro_timer.kicad_pcb]
2025-08-05 add: Layout variant 2 of PCB
    [sotpotatis_pomodoro_timer.kicad_pcb]
2025-08-05 add: Layout variant 3 of PCB
    [sotpotatis_pomodoro_timer.kicad_pcb]
2025-08-07 add: Backup progress with updated variant 1 PCB
    [sotpotatis_pomodoro_timer.kicad_pcb, sotpotatis_pomodoro_timer.kicad_sch]
2025-08-09 add: Update component placement (primarily switch+LED centering) of PCB variant 1
    [sotpotatis_pomodoro_timer.kicad_pcb]
2025-10-21 add: Final component placement (except SMD) for PCB
    [sotpotatis_pomodoro_timer.kicad_pcb, sotpotatis_pomodoro_timer.kicad_sch]
2025-10-22 fix: Remove 1M shield resistor, component relabels for better layout
    [sotpotatis_pomodoro_timer.kicad_sch]
2025-10-24 add: Backup spaghetti Charlieplexing wiring :)
    [freerouting.dsn, sotpotatis_pomodoro_timer.kicad_pcb, sotpotatis_pomodoro_timer.kicad_sch]
2026-01-20 add: Backup PCB routing progress before board reversal...
    [sotpotatis_pomodoro_timer.kicad_pcb]
2026-01-20 add: Route everything but buzzer (No reversal needed)
    [sotpotatis_pomodoro_timer.kicad_pcb]
2026-02-04 fix: Finish silkscreen time scale for LEDs
    [sotpotatis_pomodoro_timer.kicad_pcb]
2026-02-27 fix: Some silkscreen labels positioned wrong + round off board edge
    [sotpotatis_pomodoro_timer.kicad_pcb]
2026-03-25 fix: All silkscreen labels except the logo is now exactly where they should for prod.
    [sotpotatis_pomodoro_timer.kicad_pcb]
2026-04-04 fix: Small changes to silkscreen & component placement to make board look clearer
    [sotpotatis_pomodoro_timer.kicad_pcb]
2026-04-04 fix: Update board, probably ready for prod
    [sotpotatis_pomodoro_timer.kicad_pcb]
2026-05-28 add: PCB rev1.0.1: all components on one side to cut down assembly costs
    [bom.xls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]
2026-07-06 fix: Move all code to a C++ projct
    [main.cpp]
2026-07-07 fix: Refactor naming of old C/ASM code to follow style guidelines
    [hardware_constants.h, main.cpp, software_constants.h]
2026-08-05 add: Switch to C++, create a MWE of app code layout.
2026-08-05 add: PCB production files for rev1.0.1
    [PCBWay_bom.csv, PCBWay_positions.csv, bom.xls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]
